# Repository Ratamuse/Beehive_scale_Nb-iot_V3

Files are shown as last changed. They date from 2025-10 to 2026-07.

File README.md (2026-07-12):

# ⚖️ Balance Connectée NB-IoT  
### Système de pesée autonome, étanche et solaire basé sur TTGO SIM7080G







---

## 📚 Table des matières

1. [Présentation du projet](#presentation-du-projet)
2. [Composants — Boîtier électronique](#liste-des-composants-boitier-electronique)
3. [Composants — Structure de la balance](#liste-des-composants-structure-de-la-balance)
4. [Estimation des coûts (5 stations et 10 balances)](#estimation-des-couts-5-stations-et-10-balances)
5. [Étapes d’assemblage](#etapes-dassemblage)
6. [Téléchargement](#telechargement)
7. [Firmware](#firmware)
8. [Mode d'emploi](#mode-demploi)
9. [Partie Web et IoT](#web-iot)
10. [Licence](#licence)
11. [Auteur](#auteur)

---

## 🧠 Présentation du projet

Balances connectées au réseau **NB-IoT** via la carte **TTGO SIM7080G** de LilyGO.  
Cette carte embarque :

- un **MCU ESP32-S3**
- un modem **NB-IoT SIM7080G**
- un **chargeur solaire** pour batterie **18650 Li-Ion**
- un **GPS**
- une **carte SD** pour le stockage local des données

Les balances sont branchées à la TTGO via des convertisseurs **ADC 24 bits HX711**.

Pour faciliter les branchements, un **circuit imprimé dédié** est disponible en **2 versions** :

- une version à **2 convertisseurs HX711**, pour brancher jusqu’à **2 balances**
- une version à **4 convertisseurs HX711**, pour brancher jusqu’à **4 balances**

sur une même station.

Il comprend également :

- des connecteurs pour brancher une sonde **DS18B20** (température) ou **SHT41** (température et humidité), pour mesurer les conditions à l’extérieur du boîtier, voire à l’intérieur de la ruche
- un connecteur pour brancher un **pluviomètre à augets basculants**
- tous les autres connecteurs nécessaires (balances, bouton Wi-Fi, ON/OFF, LED)
- un **Attiny202** servant de watchdog à l'**ESP32-S3** en cas de plantage, et de compteur pour le pluviomètre
- un **capteur gyroscopique** pour détecter un vol
- un capteur **Bosch BME280** pour connaître la température, l’humidité à l’intérieur du boîtier et la pression atmosphérique
- un module **RTC (temps réel)** permettant de connecter en **Bluetooth** plusieurs stations esclaves à une station maîtresse sur un même rucher, une seule carte SIM étant ainsi nécessaire par rucher

👉 Ce circuit imprimé est à souder sur la carte **TTGO SIM7080G**.

🌐 Un serveur web embarqué vous permet de calibrer vos balances et de configurer l’adresse et le port pour vos messages MQTT.

<p align="center">
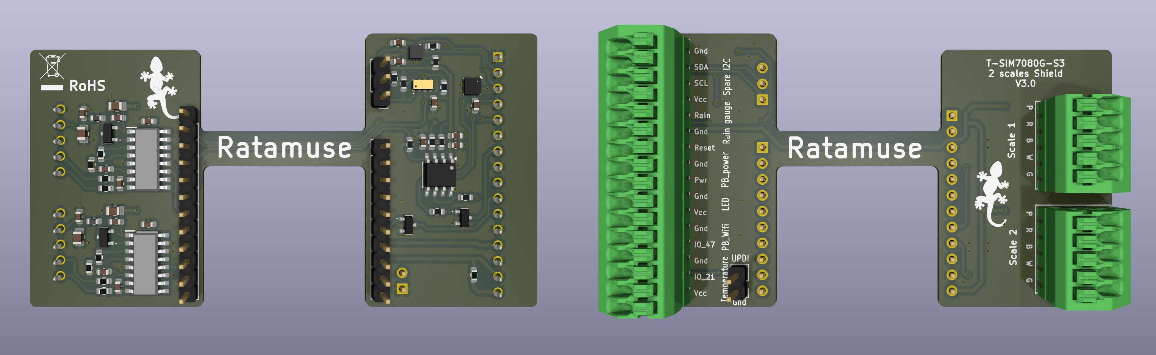
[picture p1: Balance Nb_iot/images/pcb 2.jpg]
  
  
</p>

<p align="center">
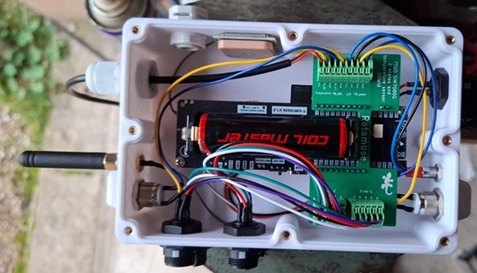
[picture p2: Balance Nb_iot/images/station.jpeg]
  
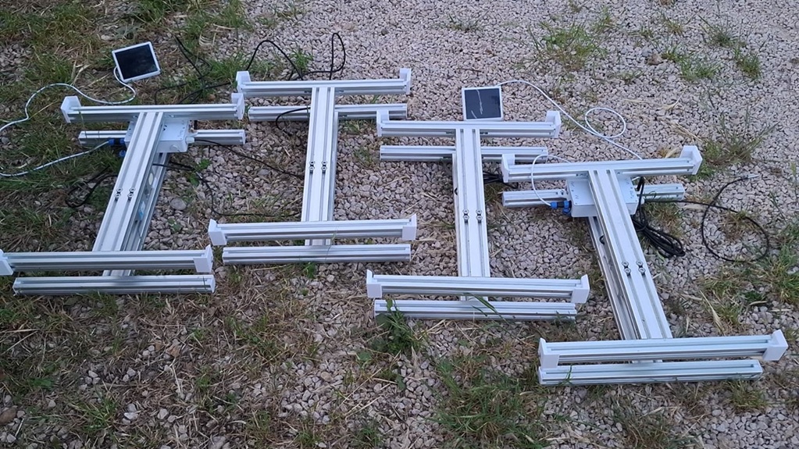
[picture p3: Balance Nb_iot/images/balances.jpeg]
  
</p>

---

## 🧩 Liste des composants – Boîtier électronique

| Image | Composant | Description | Qté | Remarques |
|:--:|---|---|:--:|---|
|  | **Carte TTGO SIM7080G (LilyGO)** | Module principal NB-IoT + ESP32 | 1 | Communication + gestion énergie |
|  | **PCB Beehive_Scale — Version 2 canaux** | Interface capteurs de charge (2× HX711) | 1 | Jusqu’à 2 balances par station |
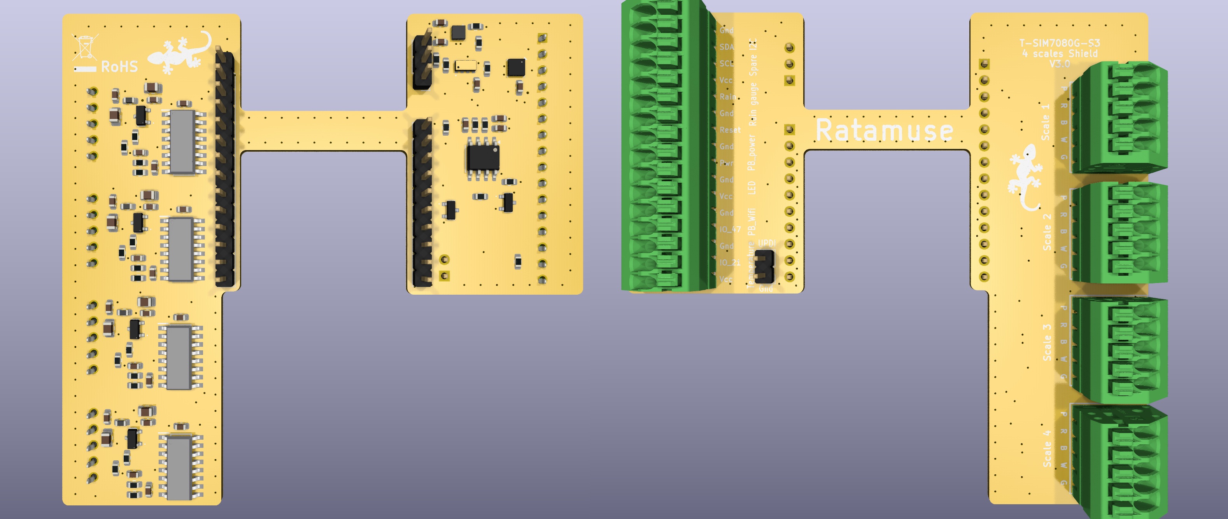
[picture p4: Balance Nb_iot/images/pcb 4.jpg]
|  | **PCB Beehive_Scale — Version 4 canaux** | Interface capteurs de charge (4× HX711) | 1 | Jusqu’à 4 balances par station |
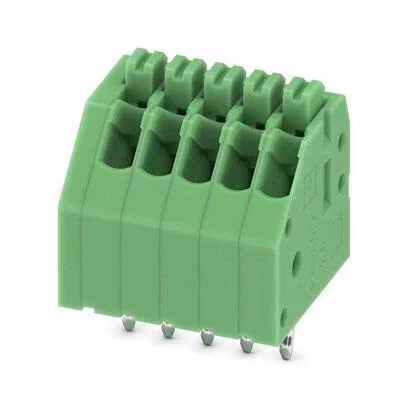
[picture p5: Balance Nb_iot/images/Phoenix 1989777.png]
|  | **Bornier Phoenix 1989777 (5 broches)** | Connexions capteurs | 2 | À souder sur le PCB |
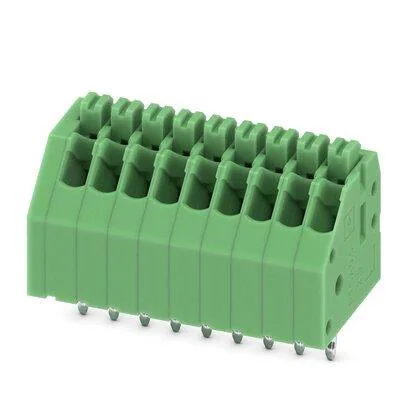
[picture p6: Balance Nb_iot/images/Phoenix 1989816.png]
|  | **Bornier Phoenix 1989816 (9 broches)** | Connexions capteurs | 1 | À souder sur le PCB |
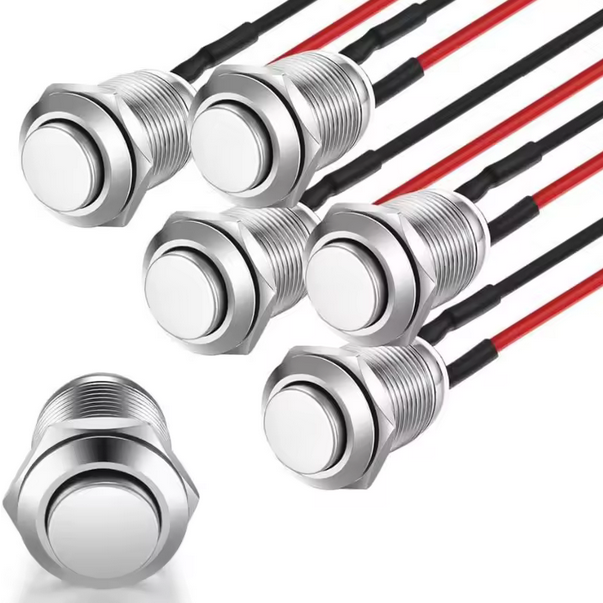
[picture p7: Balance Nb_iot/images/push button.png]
|  | **Boutons poussoirs 12 mm** | Reset / calibration | 2 | Étanches IP67 |
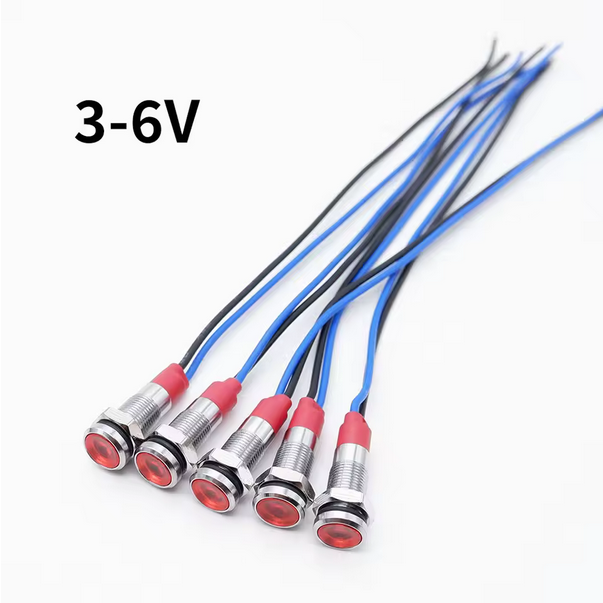
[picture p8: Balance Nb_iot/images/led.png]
|  | **LED 6 mm** | Indication d’état | 1 |  |
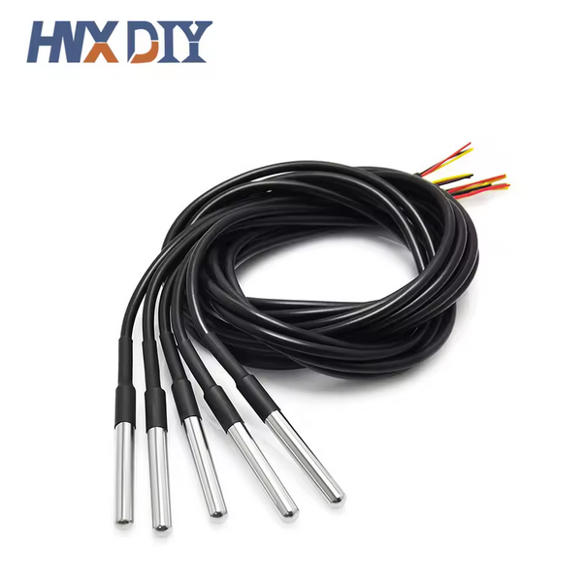
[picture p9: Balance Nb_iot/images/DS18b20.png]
|  | **Sonde DS18B20** | Température ambiante | 1 |  |
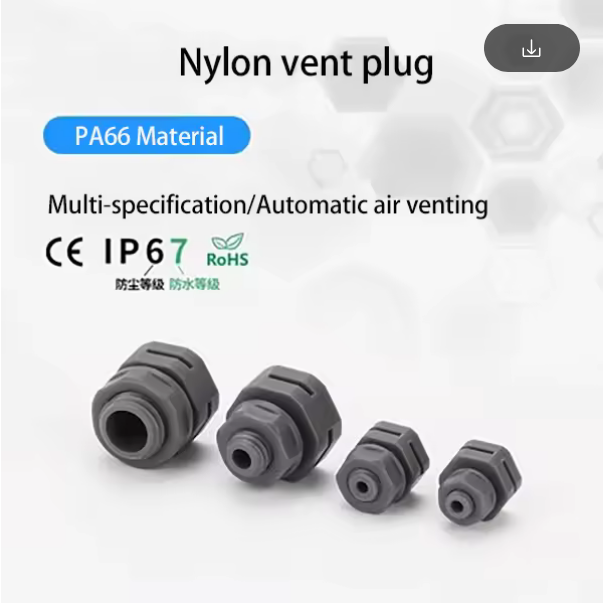
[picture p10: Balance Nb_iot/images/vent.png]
|  | **Soupape d’équilibrage** | Évite la condensation | 1 | IP67 |
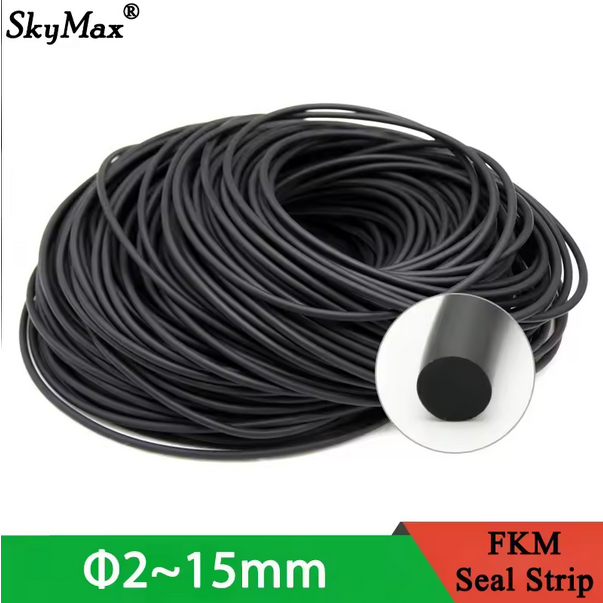
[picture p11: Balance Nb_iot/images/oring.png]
|  | **Joint torique Ø2 mm** | Étanchéité couvercle | 1 | Silicone ou nitrile |
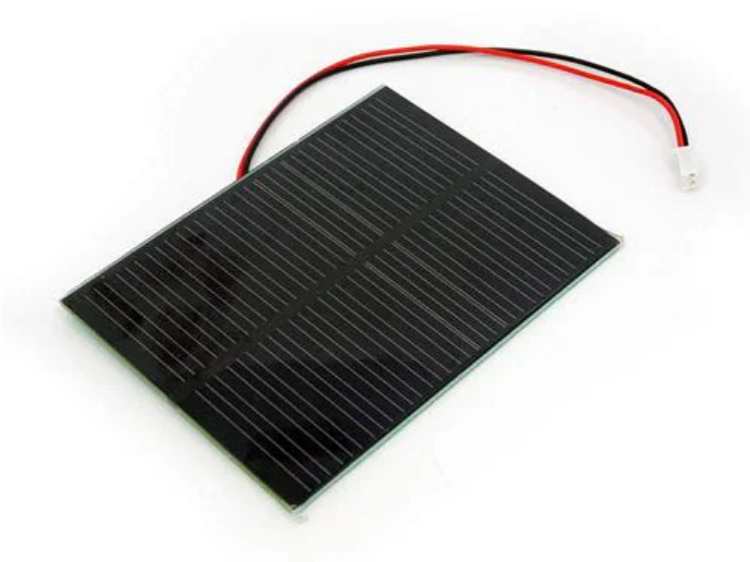
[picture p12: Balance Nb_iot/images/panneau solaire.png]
|  | **Panneau solaire 1W / 6V** | Alimentation solaire | 1 | ~100×80 mm |
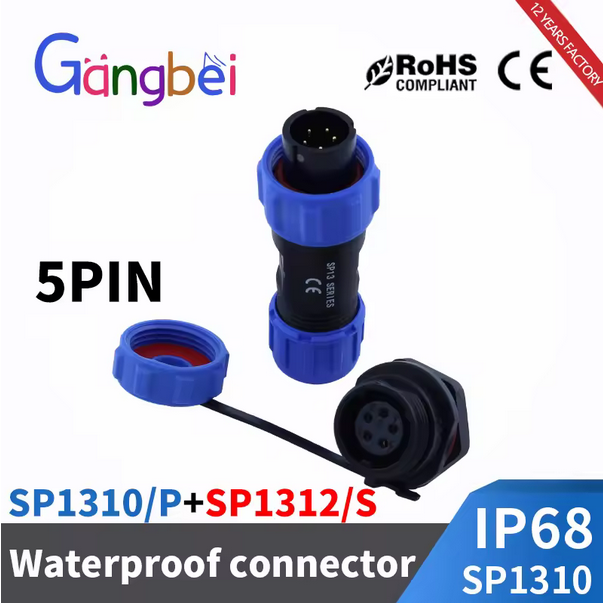
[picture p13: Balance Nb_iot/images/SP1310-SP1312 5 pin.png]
|  | **Connecteurs étanches 5 pins** | Connexion balance | 2 | IP67 |
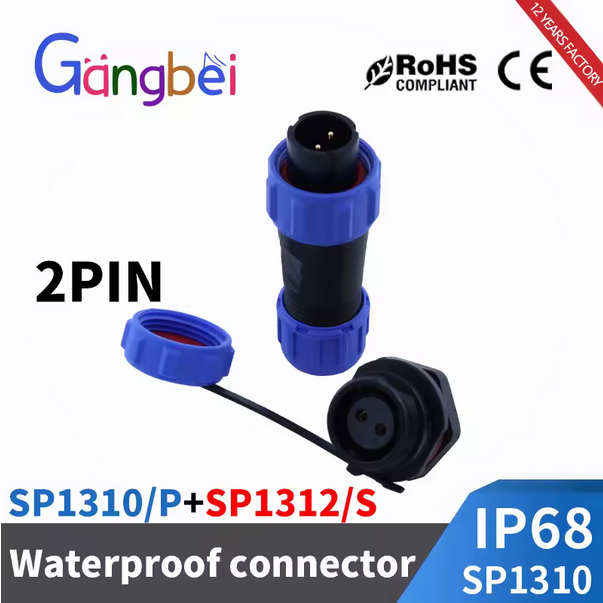
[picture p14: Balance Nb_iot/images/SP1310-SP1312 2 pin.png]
|  | **Connecteurs étanches 2 pins** | Connexion solaire | 1 | IP67 |
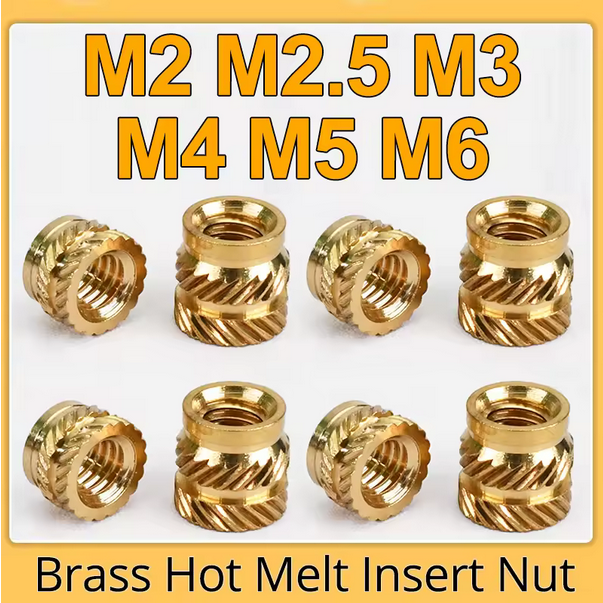
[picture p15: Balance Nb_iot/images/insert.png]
|  | **Inserts laiton ** | Fixation boîtier 3D | 6 | M3 (diam 4.2mm, hauteur 5mm), à insérer à chaud |
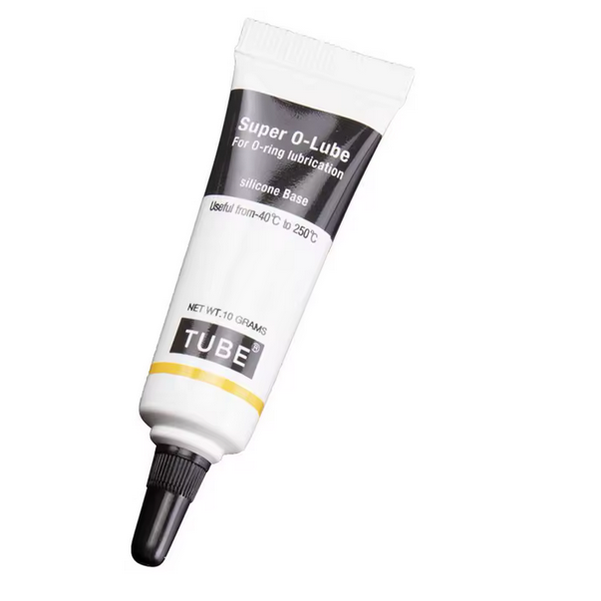
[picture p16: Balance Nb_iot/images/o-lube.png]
|  | **Graisse silicone** | Lubrification joints | - | Améliore l’étanchéité |
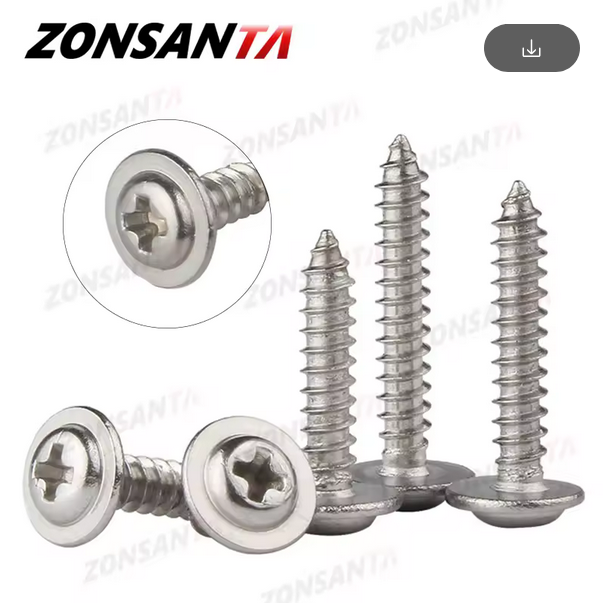
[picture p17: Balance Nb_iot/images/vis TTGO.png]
|  | **Vis de fixation TTGO** | Fixation carte | 4 | M2 5mm Inox |
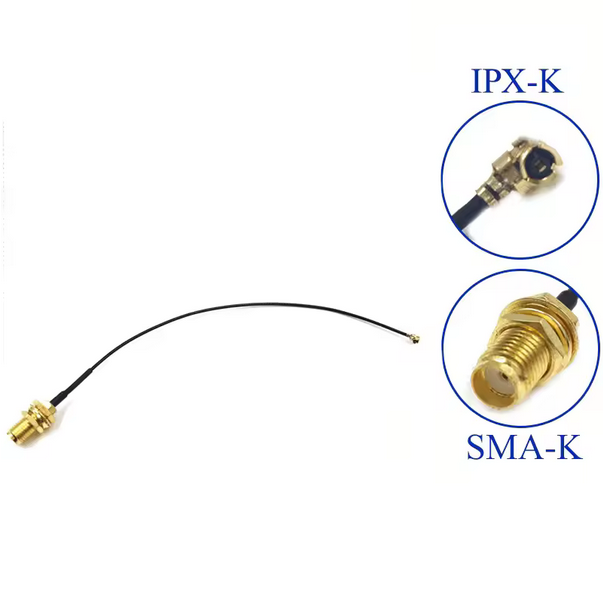
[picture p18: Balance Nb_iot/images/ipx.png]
|  | **Câble IPX → SMA-K (5 cm)** | Liaison antenne | 1 | Pour module SIM7080G |
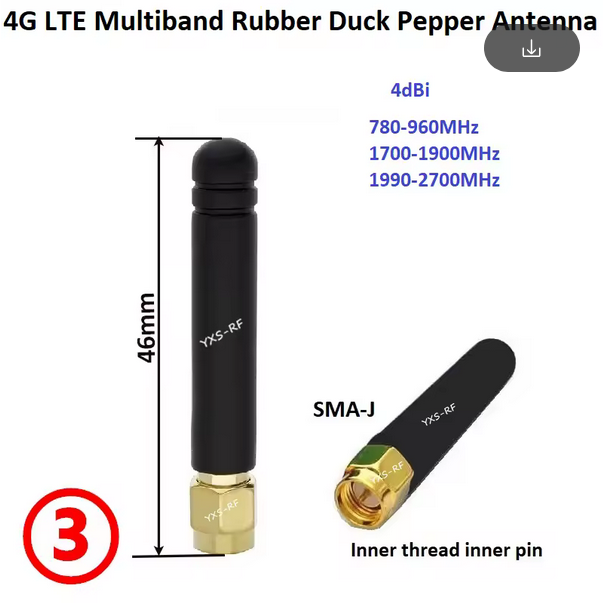
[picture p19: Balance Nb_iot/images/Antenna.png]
|  | **Antenne NB-IoT / 4G** | Transmission réseau | 1 | SMA externe |
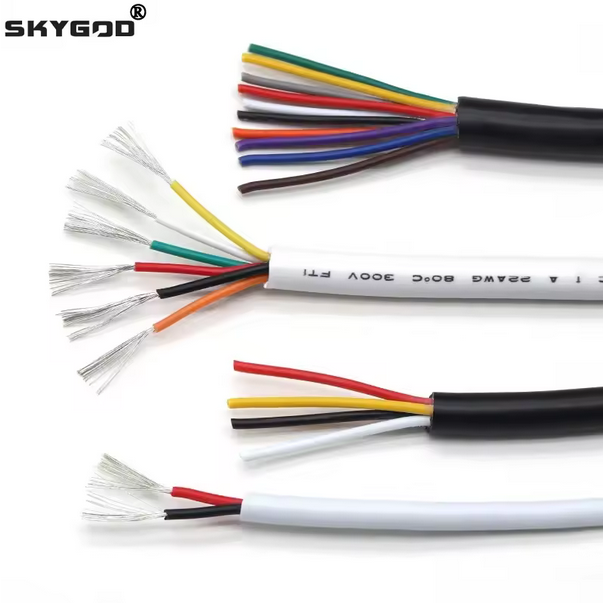
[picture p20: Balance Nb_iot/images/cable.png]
|  | **Câble 2 brins (2 m)** | Connexion solaire | 1 |  |
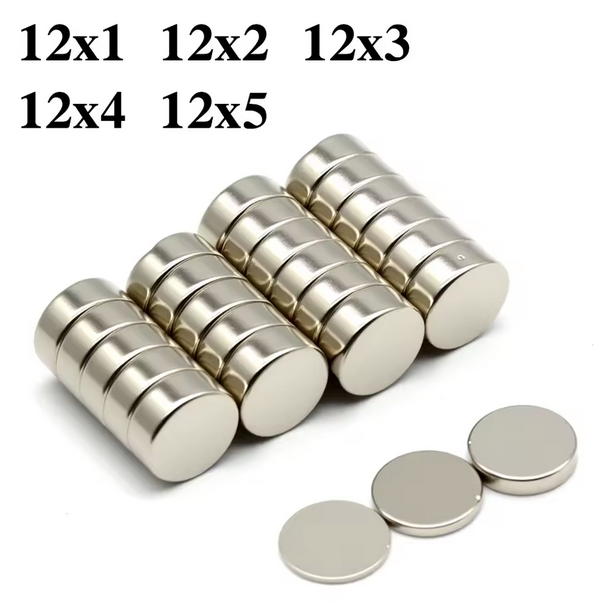
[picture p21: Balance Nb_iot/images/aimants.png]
|  | **Aimants 12×3 mm** | Fixation panneau solaire | 2 | Néodyme |
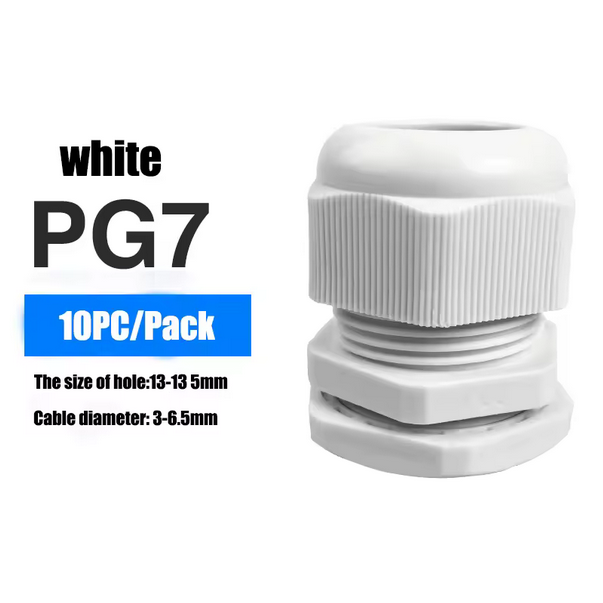
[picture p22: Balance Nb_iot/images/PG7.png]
|  | **Presse-étoupe PG7 (12 mm)** | Passage câble | 1 | IP68 |
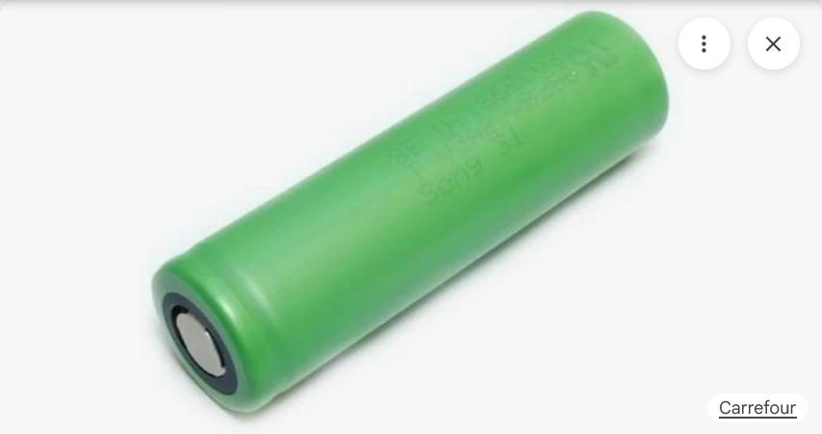
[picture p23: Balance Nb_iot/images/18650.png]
|  | **Batterie Li-Ion 18650 (3000 mAh)** | Alimentation interne | 1 |  |
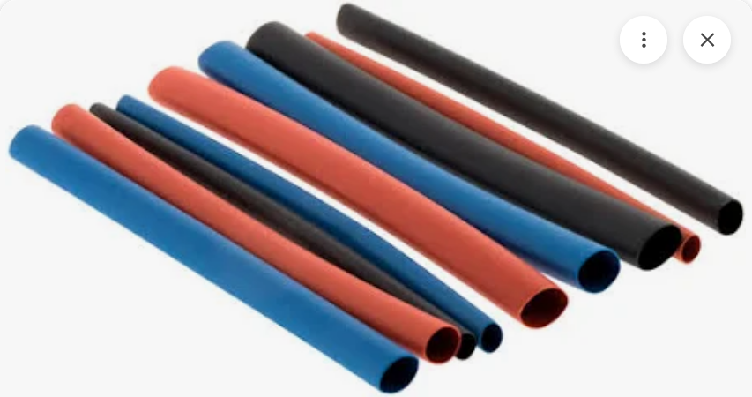
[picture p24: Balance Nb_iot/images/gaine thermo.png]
|  | **Gaine thermorétractable** | Protection connexions | - |  |
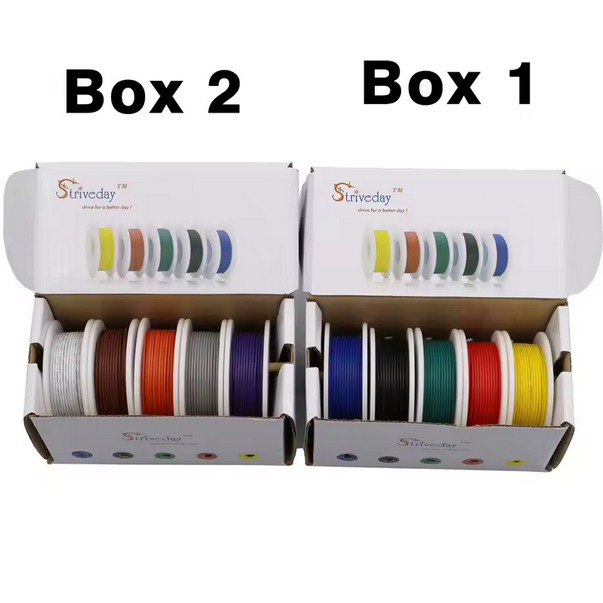
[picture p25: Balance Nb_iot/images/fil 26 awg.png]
|  | **Fils AWG26** | Câblage interne | - | LED, boutons |
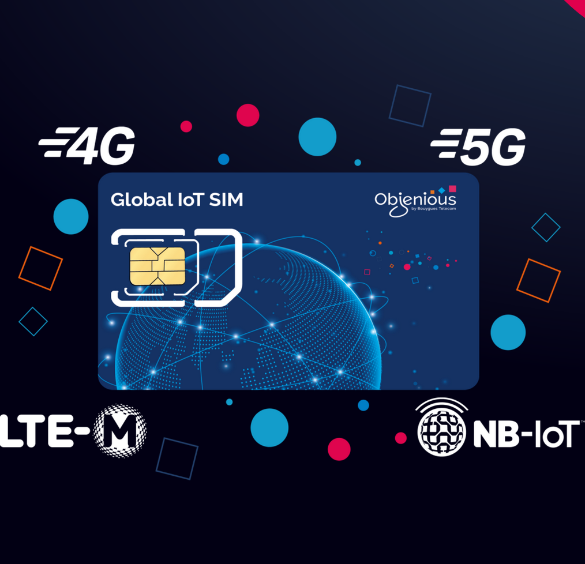
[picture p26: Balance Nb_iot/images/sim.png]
|  | **Carte SIM NB-IoT** | Accès réseau | 1 | M2M ou prépayée |
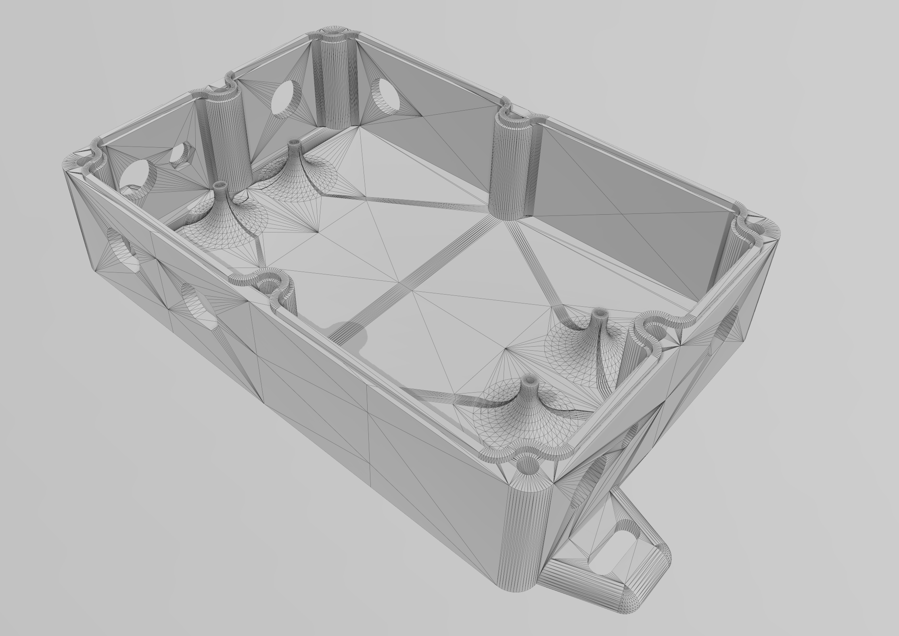
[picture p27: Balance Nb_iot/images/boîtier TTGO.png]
|  | **Boîtier imprimé 3D (PETG)** | Conteneur principal | 1 | Étanche et modulaire |

---

## ⚖️ Liste des composants – Structure de la balance

| Image | Composant | Description | Qté | Remarques |
|:--:|---|---|:--:|---|
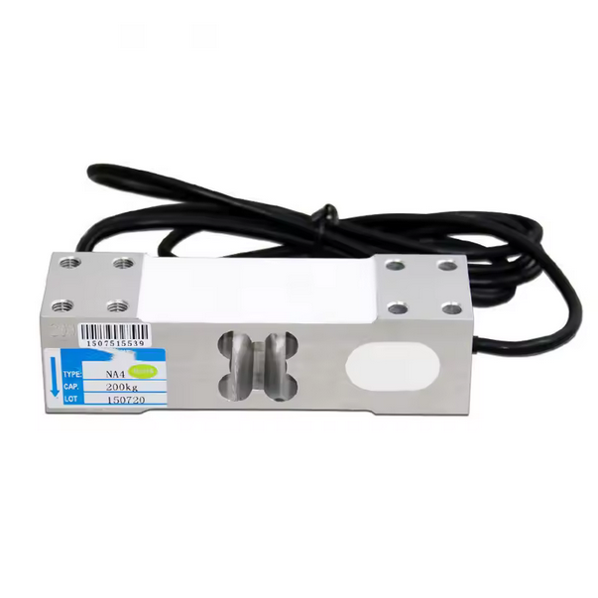
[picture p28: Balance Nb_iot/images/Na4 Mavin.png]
|  | **Capteurs de charge NA4 Mavin** | Mesure du poids | 2 | 100 ou 200 kg |
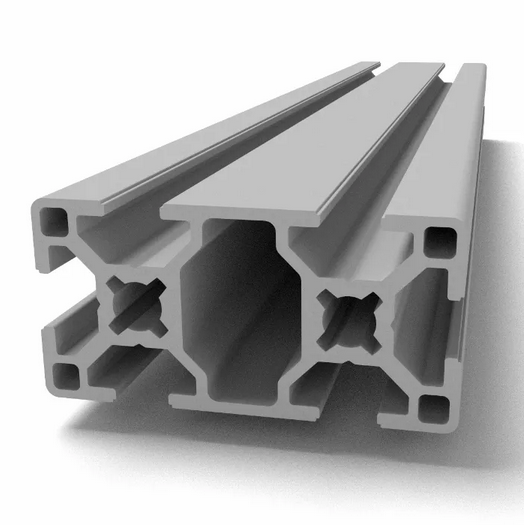
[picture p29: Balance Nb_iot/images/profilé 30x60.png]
|  | **Profilé alu 30×60 Type B** | Structure  | 2 | 480 mm (format plancher Nicot) |
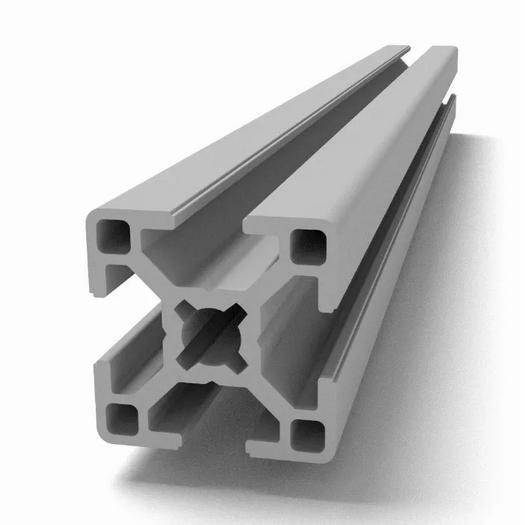
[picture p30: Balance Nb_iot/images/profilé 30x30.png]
|  | **Profilé alu 30×30 Type B** | Structure  | 4 | 430 mm (format plancher Nicot) |
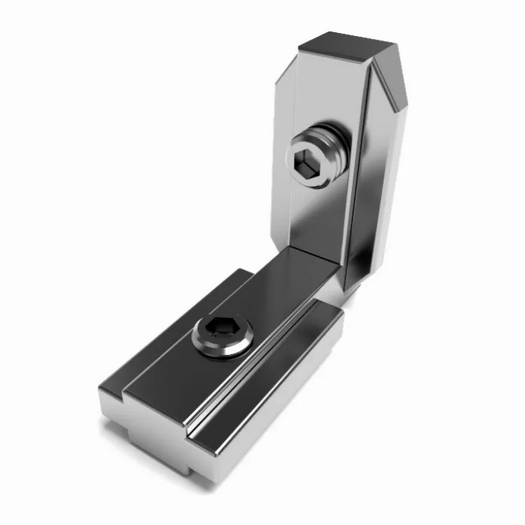
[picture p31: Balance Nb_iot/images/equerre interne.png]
|  | **Équerres internes** | Assemblage mécanique | 8 | Rainure 8 M6 |
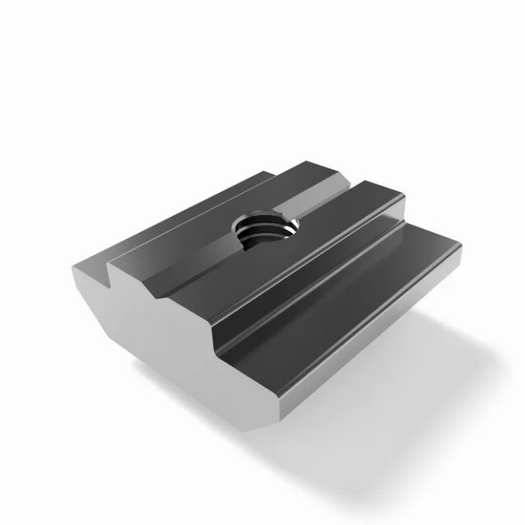
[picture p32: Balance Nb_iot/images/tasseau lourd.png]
|  | **Tasseaux lourds B-Type M5** | Fixation structurelle | 2 | Maintien |
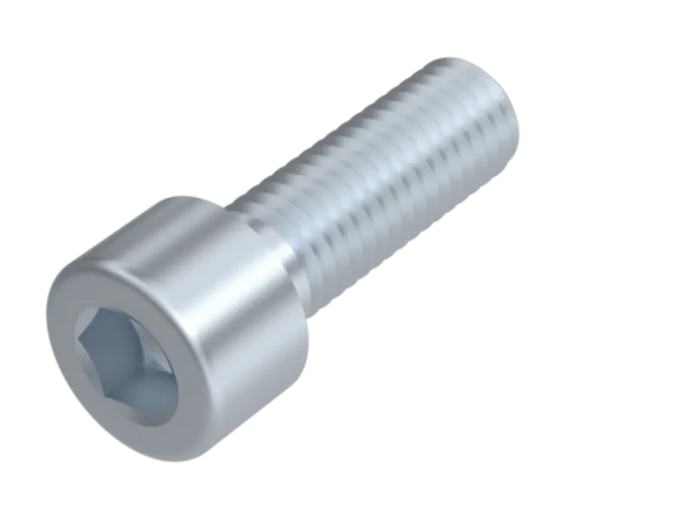
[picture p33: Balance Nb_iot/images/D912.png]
|  | **Visserie DIN 912** | M8x16 / M8x45 / M5x8 | - | Inox |
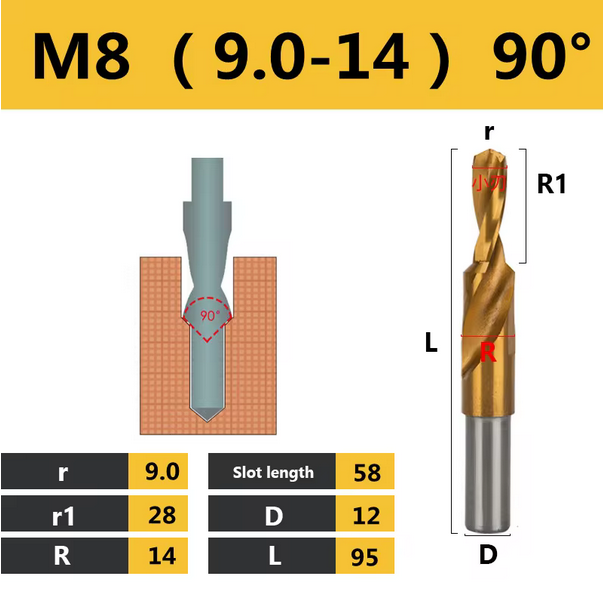
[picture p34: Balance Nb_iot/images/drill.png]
|  | **Foret étagé M8 (9–14 mm)** | Perçage profilés | 1 | |
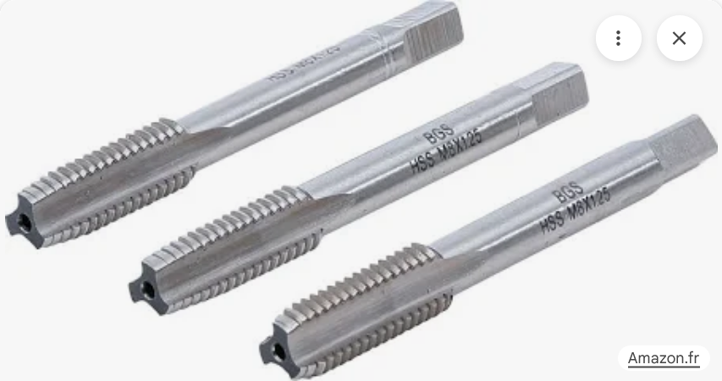
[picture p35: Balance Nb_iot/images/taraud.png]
|  | **Taraud M8** | Filetage profilés | 1 |  |
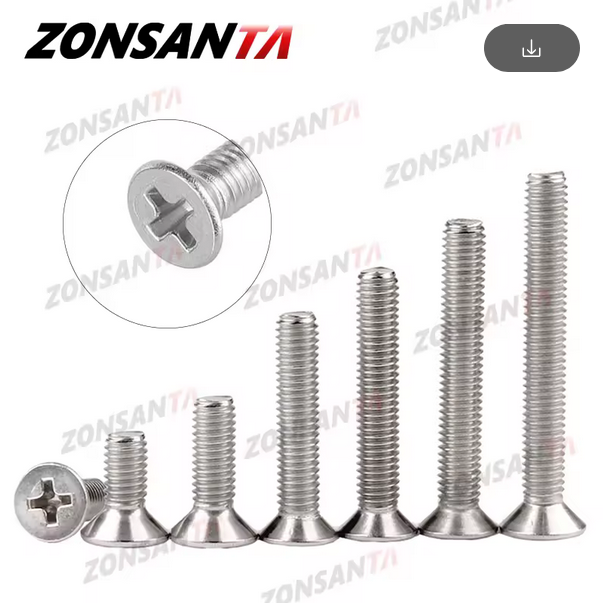
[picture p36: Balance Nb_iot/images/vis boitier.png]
|  | **Vis de boîtier** | Fixation boîtier | 4 | Inox |
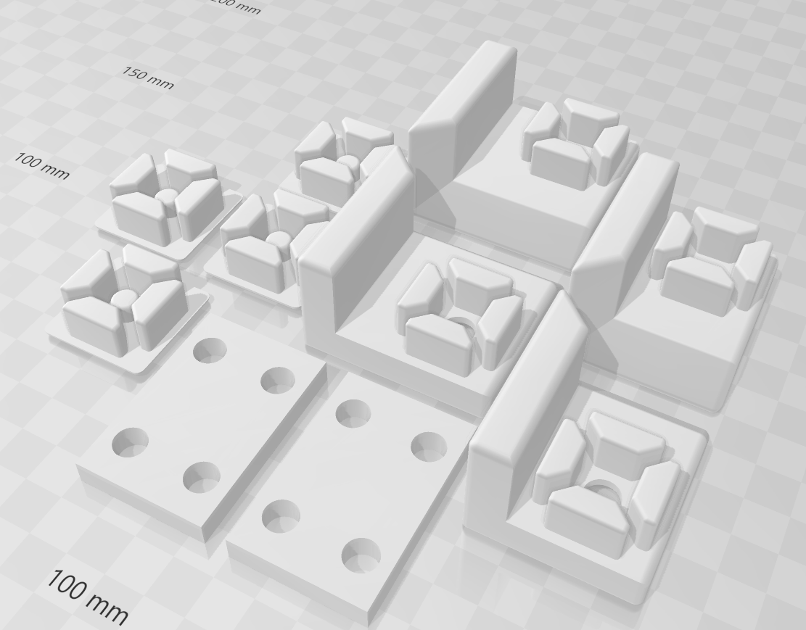
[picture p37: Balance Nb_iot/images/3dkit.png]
|  | **Kit impression 3D (PETG)** | Pièces structurelles | 1 | Supports, entretoises |

---

## 💰 Estimation des coûts — 5 stations et 10 balances (janvier 2026)

> ⚠️ Estimation indicative : les prix varient selon fournisseurs, quantités et frais de port.

### Balances (x10)

#### Motedis.fr

| Élément | Coût |
|---|---:|
| Kit Motedis | 465 € TTC |

#### Aliexpress

| Élément | Coût |
|---|---:|
| Connecteurs SP13 2 pins | 11 € |
| Connecteurs SP13 5 pins | 28 € |
| Peson 200 kg | 250 € |
| **Sous-total Balances** | **754 €** |

---

### Stations (x5)

#### Aliexpress

| Élément | Coût |
|---|---:|
| Carte TTGO SIM7080G | 200 € |
| Sonde température DS18B20 | 4,3 € |
| Câble IPX | 2,5 € |
| Antenne 4G | 4,5 € |
| Câble panneau solaire | 7 € |
| Aimant | 4,2 € |
| Reniflard | 4 € |
| Bouton poussoir | 5 € |
| Vis boîtier | 1,85 € |
| Vis TTGO | 1,8 € |
| LED rouge 3V | 6 € |
| Joint torique 2 mm × 5 m | 3,3 € |
| Câble 28 AWG | 1 € |
| Gaine thermo | 1 € |
| Colliers | 0,5 € |
| Inserts laiton | 1,8 € |

#### Mouser

| Élément | Coût |
|---|---:|
| Panneau solaire 1W | 20,5 € |
| Connecteurs 5 pins | 8 € |
| Connecteurs 12 pins | 9,7 € |
| FDP | 20 € *(ou 0 € si commande > 50 €)* |

#### JLCPCB

| Élément | Coût |
|---|---:|
| PCB | 54 € |
| *(108 € pour 10 cartes)* | |

#### Divers

| Élément | Coût |
|---|---:|
| 5 SIM NB-IoT Bouygues Telecom | 90 € |
| Impression 3D PETG | 40 € |
| Vernis de tropicalisation | 5 € |

---

### Total

| Total | Coût |
|---|---:|
| **Total global** | **1230 €** |
| **Coût moyen (par station)** | **246 €** |

---

## ⚙️ Étapes d’assemblage

*A faire.*

---

## 📥 Téléchargements

### 🔌 Fichiers PCB

- **Dossier PCB (schémas + gerbers + BOM)**  
Ancien modèle, 2 balances, un attiny202 pour le watchdog
  👉 https://github.com/Ratamuse/Beehive_scale_Nb-iot_V3/tree/main/Balance%20Nb_iot/PCB

### 🧩 Fichiers STL pour impression 3D

- **Dossier STL**  
  👉 https://github.com/Ratamuse/Beehive_scale_Nb-iot_V3/tree/main/Balance%20Nb_iot/Fichiers%20stl

---

## 💾 Firmware

- **Dossier Firmware**  
  👉 https://github.com/Ratamuse/Beehive_scale_Nb-iot_V3/tree/main/Balance%20Nb_iot/Firmware

---

## 📘 Mode d'emploi

Pour consulter le **mode d'emploi complet** de la Balance Connectée NB-IoT, rendez-vous ici :  
👉 [Mode d'emploi](https://github.com/Ratamuse/Beehive_scale_Nb-iot_V3/tree/main/Balance%20Nb_iot/Mode%20d'emploi)

## 🌐 Partie Web et IoT

La **balance connectée** communique via un **serveur web embarqué** et envoie ses données au format **MQTT** vers un **broker Mosquitto**.  

Les données envoyées par MQTT comprennent :

- ⚖️ **Poids** : mesures des deux ou quatre balances  
- 🌡️ **Température** : température ambiante mesurée par la sonde DS18B20  
- 🔋 **Batterie** : pourcentage de charge de la batterie interne  
- 📶 **Signal NB-IoT** : force du signal réseau  
- 📍 **Position** : coordonnées GPS exactes et position approximative (mise à jour 1 fois par jour)

Voici le flux des données :  

- 📨 **Envoi des mesures** : la balance publie ses données en MQTT.  
- ⚙️ **Traitement** : les messages peuvent être formatés et transformés par **Telegraf**.  
- 🗄️ **Stockage** : les données sont enregistrées dans une **base InfluxDB v2**.  
- 📊 **Visualisation** : Grafana permet de suivre les mesures en **temps réel** et d’afficher les historiques.  

> 💡 Exemple : les fichiers MQTT peuvent être traités comme vous le souhaitez, selon vos besoins.  

Toutes les données peuvent être :  

- 🖥️ **Stockées localement** sur un serveur dédié.  
- ☁️ Ou hébergées **dans le cloud** via un prestataire pour un accès distant et sécurisé.  

Cette architecture flexible permet d’**adapter le système** à différents besoins, tout en gardant la possibilité d’une **supervision centralisée ou locale**.

🌍 Un **site internet** est également disponible pour recevoir et visualiser vos données : gratuit pour les fonctionnalités de base, et entre **20 et 30€** par an pour l'accès à toutes les fonctionnalités (essai gratuit de **15 jours**). 
👉 [monrucher.ratamuse.fr](https://monrucher.ratamuse.fr)

## 📜 Licence

Ce projet est distribué sous licence **MIT**.  
Vous êtes libres de l’utiliser, le modifier et le partager, tant que la licence originale est conservée.

---

## 👤 Auteur

**Auteur :** [Ratamuse](https://github.com/Ratamuse)  
**Projet :** Balance Connectée NB-IoT  
**Version :** v1.0  
**Année :** 2026

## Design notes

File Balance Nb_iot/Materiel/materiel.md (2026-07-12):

# ⚖️ Balance Connectée NB-IoT  
### Système de pesée autonome, étanche et solaire basé sur TTGO SIM7080G







---

## 📚 Table des matières

1. [Présentation du projet](#-présentation-du-projet)
2. [Composants — Boîtier électronique](#-liste-des-composants--boîtier-électronique)
3. [Composants — Structure de la balance](#-liste-des-composants--structure-de-la-balance)
4. [Estimation des coûts (janvier 2026)](#-estimation-des-coûts--5-stations-et-10-balances-janvier-2026)
5. [Assemblage](#-étapes-dassemblage)
6. [Téléchargement](#-téléchargement)
7. [Licence](#-licence)
8. [Auteur](#-auteur)

---

## 🧠 Présentation du projet

Balances connectées au réseau **NB-IoT** via la carte **TTGO SIM7080G** de LilyGO.  
Cette carte embarque :

- un **MCU ESP32-S3**
- un modem **NB-IoT SIM7080G**
- un **chargeur solaire** pour batterie **18650 Li-Ion**
- un lecteur de **carte microSD** utile au projet

Les balances sont branchées à la TTGO via des convertisseurs **ADC 24 bits HX711**.  
Une sonde de température **DS18B20** complète l’ensemble.

Pour faciliter les branchements, un **circuit imprimé dédié** est disponible. Il comprend :

- 2 convertisseurs **HX711**
- tous les connecteurs nécessaires (balances, sonde, bouton Wi-Fi, ON/OFF, LED)
- un **watchdog externe** pour relancer la carte principale en cas de plantage

👉 Ce circuit imprimé est à souder sur la carte **TTGO SIM7080G**.

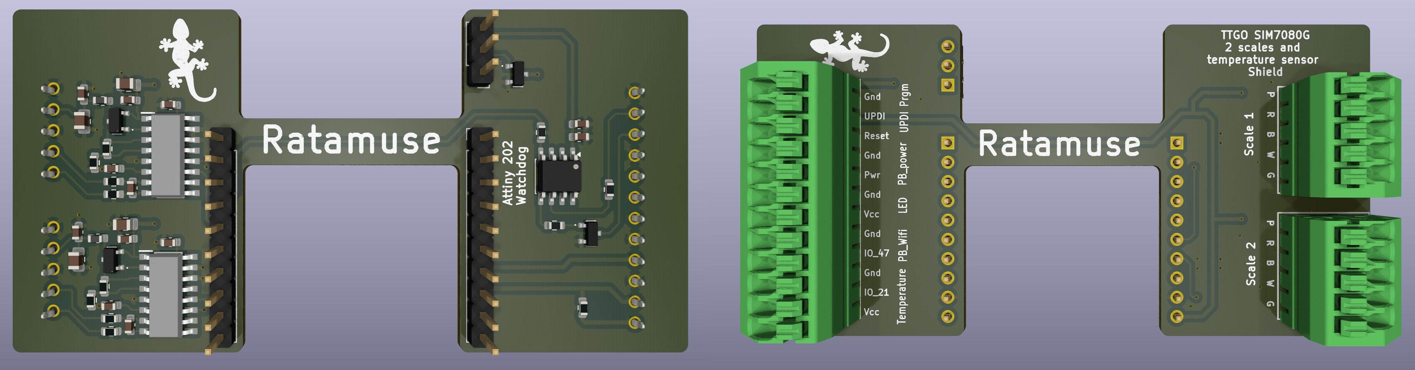
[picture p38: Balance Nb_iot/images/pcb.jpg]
PCB

TTGO

---

## 🧩 Liste des composants – Boîtier électronique

| Image | Composant | Description | Qté | Remarques |
|:--:|---|---|:--:|---|
|  | **Carte TTGO SIM7080G (LilyGO)** | Module principal NB-IoT + ESP32 | 1 | Communication + gestion énergie |
|  | **PCB Beehive_Scale** | Interface capteurs de charge | 1 | Spécifique au projet |
|  | **Bornier Phoenix 1989777 (5 broches)** | Connexions capteurs | 2 | À souder sur le PCB |
|  | **Bornier Phoenix 1989816 (9 broches)** | Connexions capteurs | 1 | À souder sur le PCB |
|  | **Boutons poussoirs 12 mm** | Reset / calibration | 2 | Étanches IP67 |
|  | **LED 6 mm** | Indication d’état | 1 | Couleur libre |
|  | **Sonde DS18B20** | Température ambiante | 1 | Étanche |
|  | **Soupape d’équilibrage** | Évite la condensation | 1 | IP67 |
|  | **Joint torique Ø2 mm** | Étanchéité couvercle | 1 | Silicone ou nitrile |
|  | **Panneau solaire 1W / 6V** | Alimentation solaire | 1 | ~100×80 mm |
|  | **Connecteurs étanches 5 pins** | Connexion balance | Plusieurs | IP67 |
|  | **Connecteurs étanches 2 pins** | Connexion solaire | Plusieurs | IP67 |
|  | **Inserts laiton M3** | Fixation boîtier 3D | 6 | À insérer à chaud |
|  | **Graisse silicone** | Lubrification joints | - | Améliore l’étanchéité |
|  | **Vis de fixation TTGO** | Fixation carte | 4 | Inox |
|  | **Câble IPX → SMA-K (5 cm)** | Liaison antenne | 1 | Pour module SIM7080G |
|  | **Antenne NB-IoT / 4G** | Transmission réseau | 1 | SMA externe |
|  | **Câble 2 brins (2 m)** | Connexion solaire | 1 | Étanche |
|  | **Aimants 12×3 mm** | Fixation panneau solaire | 2 | Néodyme |
|  | **Presse-étoupe PG7 (12 mm)** | Passage câble | 1 | IP68 |
|  | **Batterie Li-Ion 18650 (3000 mAh)** | Alimentation interne | 1 | Avec BMS |
|  | **Gaine thermorétractable** | Protection connexions | - | Étanchéité |
|  | **Fils AWG26** | Câblage interne | - | LED, boutons |
|  | **Vis de boîtier** | Fixation boîtier | 4 | Inox M3x12mm |
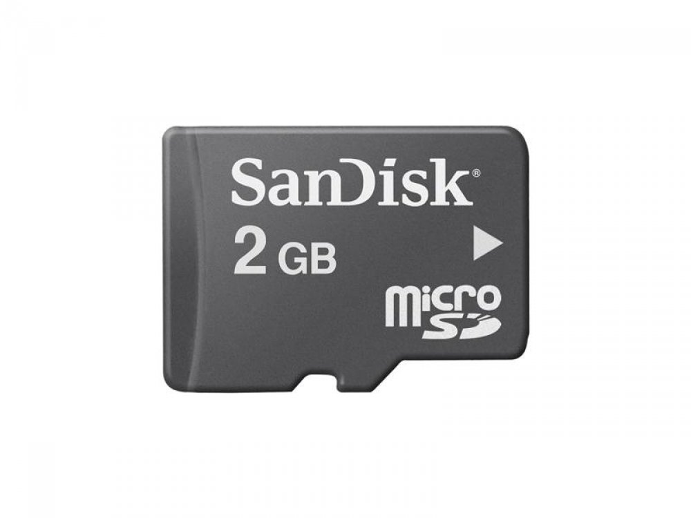
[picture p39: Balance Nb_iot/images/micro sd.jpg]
|  | **Carte microSD 16 Go** | Stockage local | 1 | FAT32 |
|  | **Carte SIM NB-IoT** | Accès réseau | 1 | M2M ou prépayée |
|  | **Boîtier imprimé 3D (PETG)** | Conteneur principal | 1 | Étanche et modulaire |

---

## ⚖️ Liste des composants – Structure de la balance

| Image | Composant | Description | Qté | Remarques |
|:--:|---|---|:--:|---|
|  | **Capteurs de charge NA4 Mavin** | Mesure du poids | 2 | 100 ou 200 kg |
|  | **Profilé alu 30×60 Type B** | Structure principale | 2 | 480 mm |
|  | **Profilé alu 30×30 Type B** | Structure secondaire | 4 | 430 mm |
|  | **Équerres internes** | Assemblage mécanique | 8 | Rainure 8 M6 |
|  | **Tasseaux lourds B-Type M5** | Fixation structurelle | 2 | Maintien |
|  | **Visserie DIN 912** | M8x16 / M8x45 / M5x8 | - | Inox |
|  | **Foret étagé M8 (9–14 mm)** | Perçage profilés | 1 | |
|  | **Taraud M8** | Filetage profilés | 1 | Montage précis |
|  | **Kit impression 3D (PETG)** | Pièces structurelles | 1 | Supports, entretoises |

---

## 💰 Estimation des coûts — 5 stations et 10 balances (janvier 2026)

> ⚠️ Estimation indicative : les prix varient selon fournisseurs, quantités et frais de port.

### Balances (x10)

#### Motedis.fr

| Élément | Coût |
|---|---:|
| Kit Motedis | 465 € TTC |

#### Aliexpress

| Élément | Coût |
|---|---:|
| Connecteurs SP13 2 pins | 11 € |
| Connecteurs SP13 2 pins | 28 € |
| Peson 200 kg | 250 € |
| **Sous-total Balances** | **754 €** |

---

### Stations (x5)

#### Aliexpress

| Élément | Coût |
|---|---:|
| Carte TTGO SIM7080G | 200 € |
| Sonde température DS18B20 | 4,3 € |
| Câble IPX | 2,5 € |
| Antenne 4G | 4,5 € |
| Câble panneau solaire | 7 € |
| Aimant | 4,2 € |
| Reniflard | 4 € |
| Bouton poussoir | 5 € |
| Vis boîtier | 1,85 € |
| Vis TTGO | 1,8 € |
| LED rouge 3V | 6 € |
| Joint torique 2 mm × 5 m | 3,3 € |
| Câble 28 AWG | 1 € |
| Gaine thermo | 1 € |
| Colliers | 0,5 € |
| Inserts laiton | 1,8 € |

#### Mouser

| Élément | Coût |
|---|---:|
| Panneau solaire 1W | 20,5 € |
| Connecteurs 5 pins | 8 € |
| Connecteurs 12 pins | 9,7 € |
| FDP | 20 € *(ou 0 € si commande > 50 €)* |

#### JLCPCB

| Élément | Coût |
|---|---:|
| PCB | 54 € |
| *(108 € pour 10 cartes)* | |

#### Divers

| Élément | Coût |
|---|---:|
| 5 SIM NB-IoT Bouygues Telecom | 90 € |
| Impression 3D PETG | 40 € |
| Vernis de tropicalisation | 5 € |

---

### Total

| Total | Coût |
|---|---:|
| **Total global** | **1230 €** |
| **Coût moyen (par station)** | **246 €** |

---

## ⚙️ Étapes d’assemblage

*A faire.*

---

## 📥 Téléchargements

### 🔌 Fichiers PCB

- **Dossier PCB (schémas + gerbers + BOM)**  
  👉 https://github.com/Ratamuse/Beehive_scale_Nb-iot_V3/tree/main/Balance%20Nb_iot/PCB

---

### 🧩 Fichiers STL pour impression 3D

- **Dossier STL**  
  👉 https://github.com/Ratamuse/Beehive_scale_Nb-iot_V3/tree/main/Balance%20Nb_iot/Fichiers%20stl

---

## 📜 Licence

Ce projet est distribué sous licence **MIT**.  
Vous êtes libres de l’utiliser, le modifier et le partager, tant que la licence originale est conservée.

---

## 👤 Auteur

**Auteur :** [Ratamuse](https://github.com/Ratamuse)  
**Projet :** Balance Connectée NB-IoT  
**Version :** v1.0  
**Année :** 2025

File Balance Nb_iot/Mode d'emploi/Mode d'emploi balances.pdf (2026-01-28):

# Balances connectées

Le système est composé d’un boîtier rassemblant l’électronique et de 2 balances.

Sur le boîtier :

- Un bouton poussoir ON/OFF
- Un bouton poussoir Wifi
- Une led
- Un connecteur SMA pour une antenne externe
- Une sonde de température DS18b20
- Une soupape à membrane respirante
- Un connecteur 2 broches pour panneau photovoltaïque (PV)
- Un connecteur pour la balance 1 ou A
- Un connecteur pour la balance 2 ou B

Le boîtier est fixé sur la balance A

Pour allumer le système, appuyer sur le bouton ON/OFF pendant deux secondes. La led rouge va clignoter.
Pour éteindre le système, appuyer sur le bouton ON/OFF pendant plus de six secondes. Il n’y a pas de clignotement de la led.

### Serveur web embarqué

Afin de configurer les balances, il faut accéder au serveur web embarqué.
1. Éteindre la balance en appuyant plus de 6 secondes sur le bouton ON/OFF.
2. Appuyer sur le bouton Wifi puis en même temps, appuyer sur le bouton ON/OFF. La led va clignoter, relâcher le bouton Wifi.
3. Recherche le réseau Wifi balanceS1 ou balanceS2
4. Se connecter au réseau wifi avec le mot de passe
123456789
5. Se connecter au serveur en écrivant sur la barre d’adresse d’un navigateur l’adresse IP http://192.168.4.1 (attention à ne pas écrire https://) La page principale s’affiche :

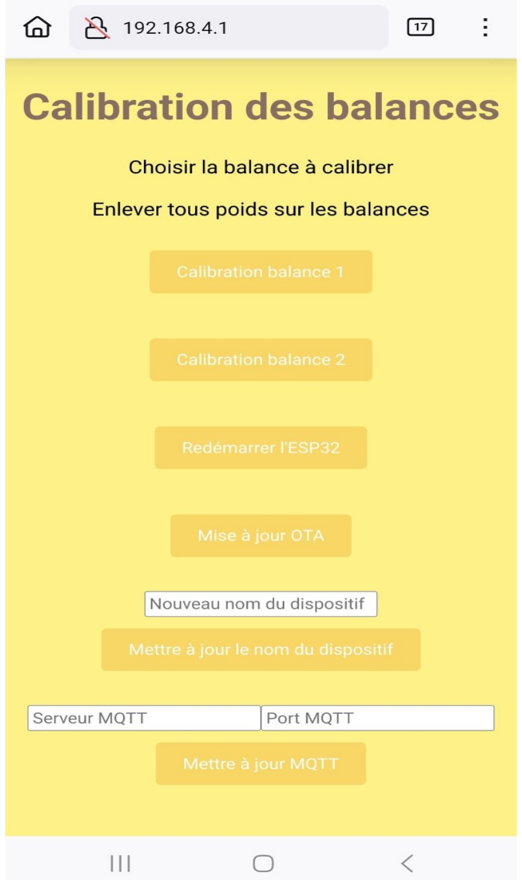
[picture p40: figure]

Si cela ne fonctionne pas, coupez les données 4G du téléphone, le naviagateur peux essayer de se connecter sur le réseau au lieu de se connecter au wifi.
Six actions sont possibles :
Calibrer la balance 1 (A)
Calibrer la balance 2 (B)
Redémarrer la station
Mettre à jour le Firmware (Mise à jour OTA) Changer le nom de la station : S1, S2, S3 etc. Changer l’adresse et le port du serveur MQTT

### Calibration des balances

Avec le temps, le zéro des balances peut dériver. Il est conseillé de calibrer la balance au moins une fois par an. Pour cela :
Pour la balance 1 (A), enlever les poids sur la balance (ruche, saleté, cordons).
Appuyer sur le bouton « Calibration balance 1 »
Une fois la page avec la valeur de l’offset affiché, poser un poid connu sur la balance à calibrer puis rentrer cette valeur en gramme. Ici 4690 grammes.
Valider en appuyant sur le bouton « Entrer »
Une fois la calibration terminée, le facteur de conversion et l’offset sont affichés.
Il y a ensuite deux possibilités, redémarrer la station ou retourner à la page d’accueil du serveur web.
La manipulation est identique pour la balance 2 (ou B)

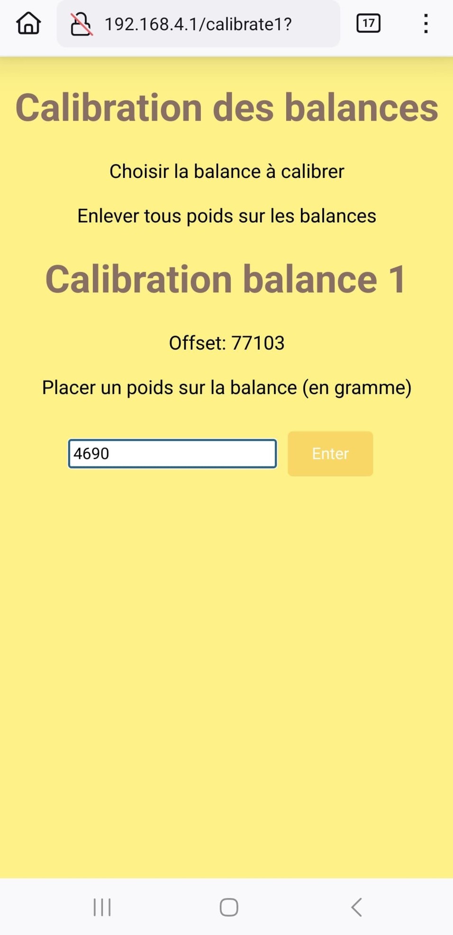
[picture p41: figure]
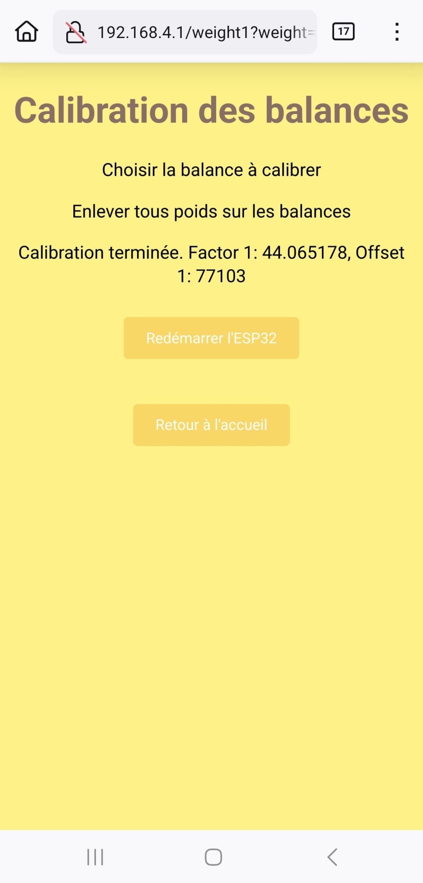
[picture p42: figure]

### Mise à jour OTA (over the air)

Il est possible d’améliorer les performances ou ajouter des fonctionnalités aux balances en mettant à jour le firmware. Pour cela, vous seriez amenés à télécharger un fichier « update.bin » et l’envoyer sur la station.
Pour cela, cliquer sur l’onglet « Mise à jour OTA » sur la page principale puis sur l’onglet « Select File» de la page ElegantOTA Lite.
Récupérer le fichier « update.bin » sur votre smartphone ou ordinateur puis valider.
Le station devrait redémarrer après la mise à jour.

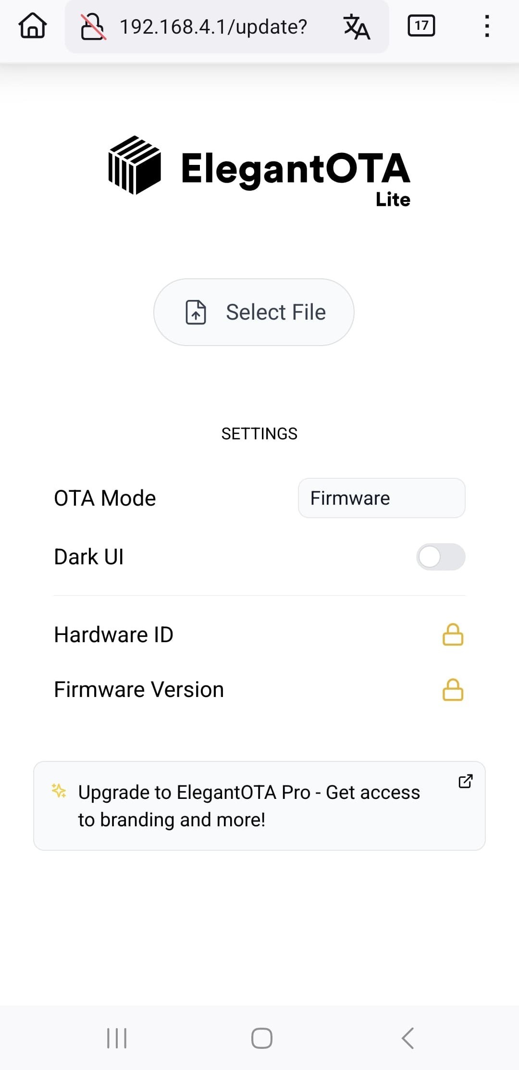
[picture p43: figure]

### Mise à jour du nom des balances

Afin de pouvoir identifier les balances sur internet, chaque station et balance sont nommées d’un identifiant unique. Le code étant commun à toute les balances, un nom est donné à la première utilisation. Ce nom reste en mémoire, même après une mise à jour du code.
Attention : Si vous changez le nom de la station, les valeurs des balances ne seront plus consultable à distance.

### Mise à jour du serveur et port MQTT :

Fonctionnement actuel (mai 2025) :
Envoi des données par Nb-iot via le réseau Bouygues Telecom (abonnement sim à renouveler tous les ans)
Broker MQTT Mosquitto privé herbergé sur un raspberry pi 5.
Transmission via le module Telegraf des données vers la base de données Influxdb V2 herbergée sur un raspberry pi 5.
Visualisation sur Grafana dans le cloud. Grafana, vient récupérer les données sur le raspberry 5.

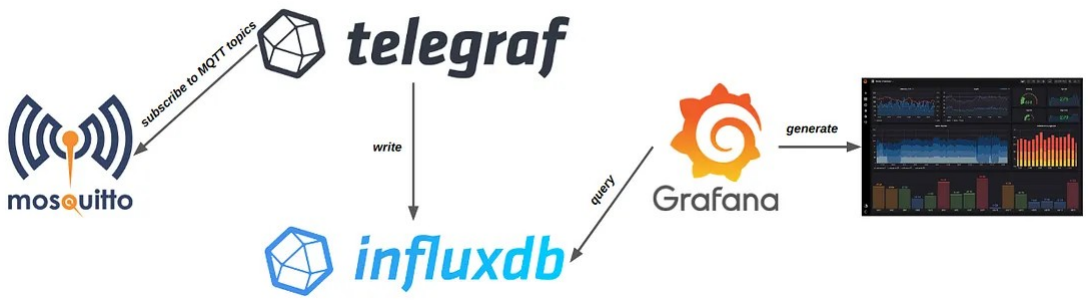
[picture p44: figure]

Cette solution de stockage de données et visualisation est donc « gratuite » pour l’utilisateur et je supporte seul le coup du matériel. Vous voulez me payer un café, mon lien paypal ci dessous, merci !
https://paypal.me/GNUVarioE?country.x=FR&locale.x=fr_FR

Si vous ne souhaitez plus passer par ce système, créer votre propre installation ou passer par une solution 100 % cloud mais probablement payante, vous pouvez modifier l’adresse et le port du broker MQTT.

### Divers :

Après chaque émission, la station se met en mode sommeil profond afin d’économiser de la batterie. Après chaque émission, la led clignote.
La fréquence des émissions est fonction de la charge de la batterie :
30 minutes de 100 % à 76 %
2h entre 75 % et 51 %
6h entre 50 % et 26 %
12 h sous les 25 %
Pensez à positionner le panneau solaire sur le toit de la ruche, face du panneau vers le sud.

Il est possible que dans certaines conditions, la station ait du mal à se connecter au réseau GSM. Dans ce cas, pour ne pas vider la batterie, la station se met en sommeil profond au bout de 60s.
Si la station ne se connecte jamais, il est possible de déconnecter la petite antenne et de la remplacer par une antenne plus grande avec un long fil. Vous pourrez ainsi essayer d’accrocher l’antenne un point plus haut (toit de la ruche, branche…).

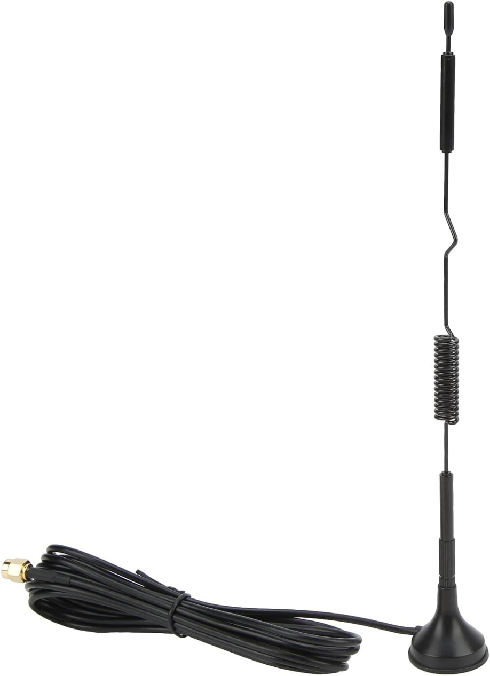
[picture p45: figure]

Les cellules des balances supportent 100kg. Elles fonctionneront avec un peu plus dessus mais pensez lorsque vous les changez de place à vérifier les vis de fixation ( les 8 vis M6 sur les pesons et les vis des équerres entre les profilés alu).
Si les balances ne sont pas utilisées, éteigniez les et gardez les à l’ombre pour ne pas exposer inutilement le boîtier au soleil.
Si vous déconnectez les balances ou le panneau solaire, pensez à obturer les connecteurs avec leur capuchon afin de les protéger.

Bref, prenez soin de votre matériel.

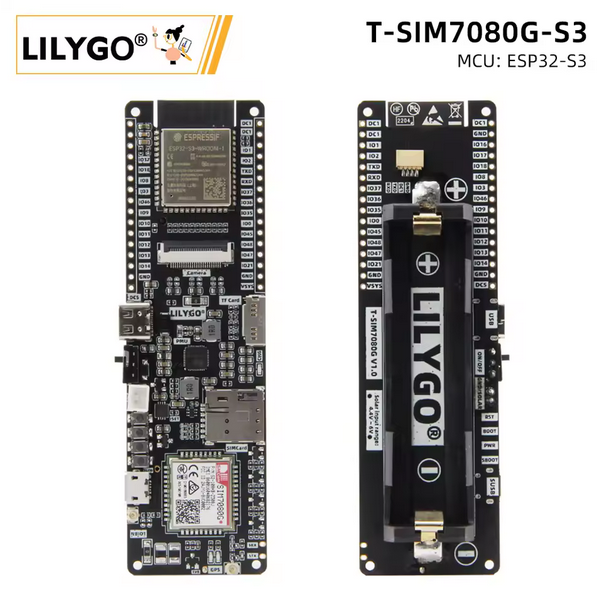
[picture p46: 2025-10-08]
Balance Nb_iot/images/TTGO.png

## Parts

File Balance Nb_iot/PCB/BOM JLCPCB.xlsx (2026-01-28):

Comment | Designator | Footprint | JLCPCB Part #（optional）
Conn_01x12 | J3 | 1989845 | C17674443
ATtiny202-SS | U1 | SOIC-8_3.9x4.9mm_P1.27mm | C2052951
4.7k | R12,R10,R1 | R_0603_1608Metric | C513565
1k | R11 | R_0603_1608Metric | C110776
PMBT2222A,215 | Q4,Q1 | PMBT2222A215 | C23869
1µF/16V | C16 | C_0603_1608Metric | C161212
0.1µF | C7,C2,C6,C9,C11,C10,C5,C12,C8,C1,C15 | C_0603_1608Metric | C45000
10µF | C13,C4,C3,C14 | C_0805_2012Metric | C408142
HX711 | IC2,IC1 | SOIC127P600X160-16N | C43656
MMBT4403 | Q2,Q3 | PMBT2222A215 | C78864
100 | R9,R8,R5,R4 | R_0603_1608Metric | C122970
20K | R6,R2 | R_0603_1608Metric | C723637
8.2K | R3,R7 | R_0603_1608Metric | C861589
3.3µH | L1,L2 | L_0603_1608Metric | C1857984
Conn_01x05 | J14,J12 | 1989777 | C17643135

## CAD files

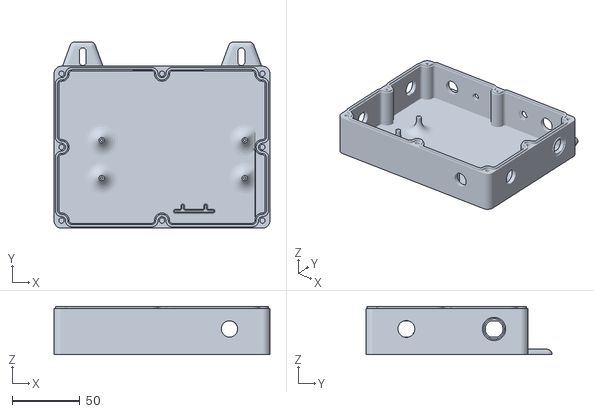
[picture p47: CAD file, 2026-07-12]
Balance Nb_iot/Fichiers stl/Boitier TTGO V4.STL
160.0 x 138.0 x 35.7

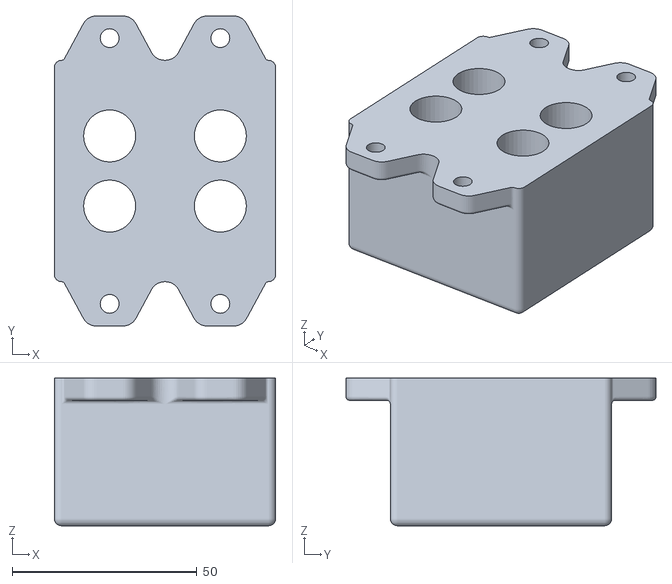
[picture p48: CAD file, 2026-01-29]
Balance Nb_iot/Fichiers stl/Gabarit de perçage.STL
60.0 x 84.0 x 40.0

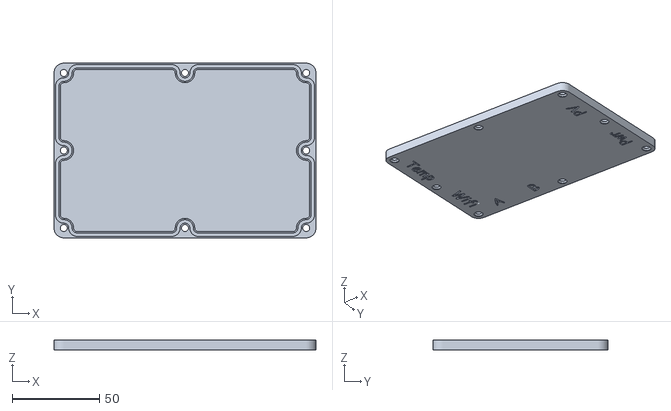
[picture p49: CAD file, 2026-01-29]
Balance Nb_iot/Fichiers stl/Couvercle TTGO.STL
150.0 x 100.0 x 6.00

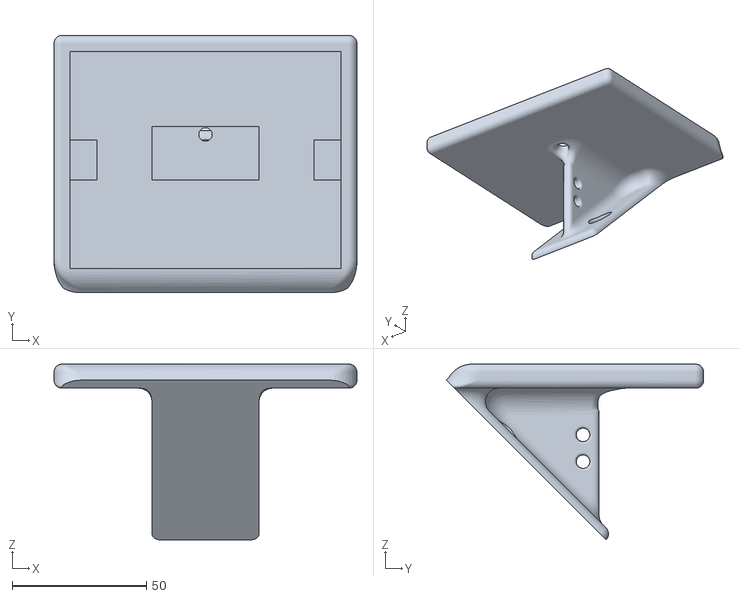
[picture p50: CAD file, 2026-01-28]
Balance Nb_iot/Fichiers stl/Support panneau solaire.STL
113.0 x 96.0 x 65.6

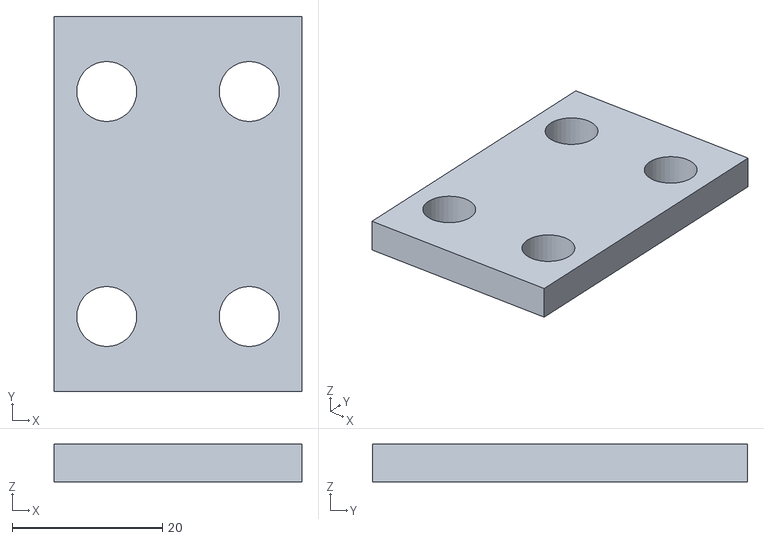
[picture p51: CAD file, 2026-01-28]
Balance Nb_iot/Fichiers stl/Entretoise balance.STL
33.0 x 50.0 x 5.00

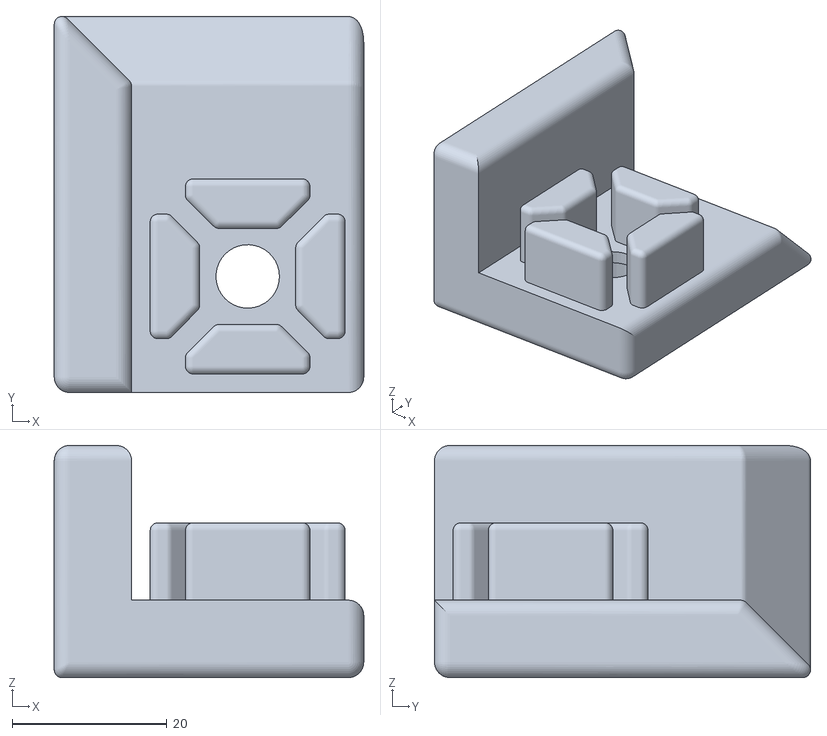
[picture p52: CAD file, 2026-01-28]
Balance Nb_iot/Fichiers stl/Blocage plateau AR court G.STL
40.0 x 48.6 x 30.0

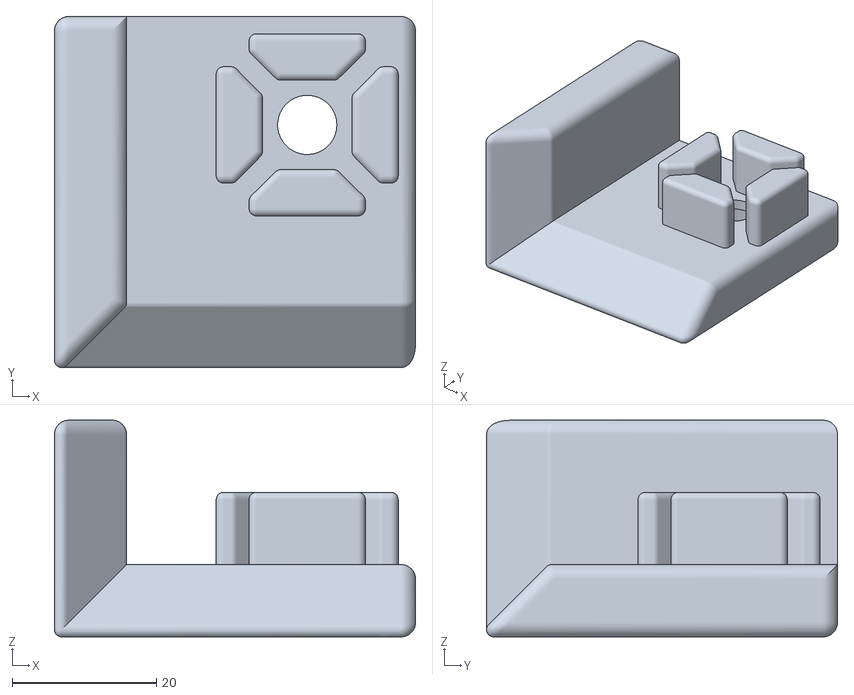
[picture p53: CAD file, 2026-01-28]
Balance Nb_iot/Fichiers stl/Blocage plateau AR long D.STL
50.0 x 48.6 x 30.0

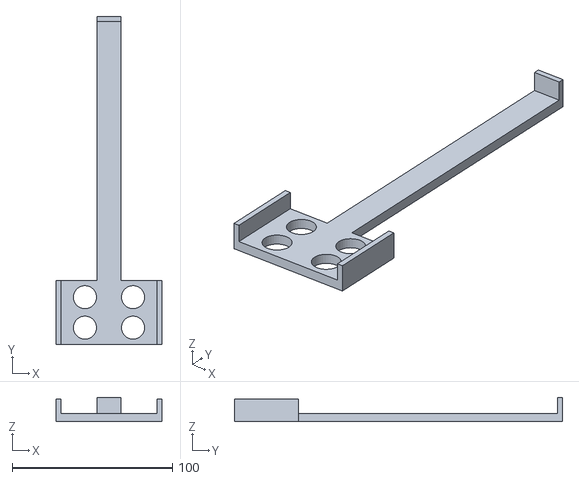
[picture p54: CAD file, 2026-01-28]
Balance Nb_iot/Fichiers stl/gabarit percage profilé 14mm.STL
66.0 x 204.5 x 15.0

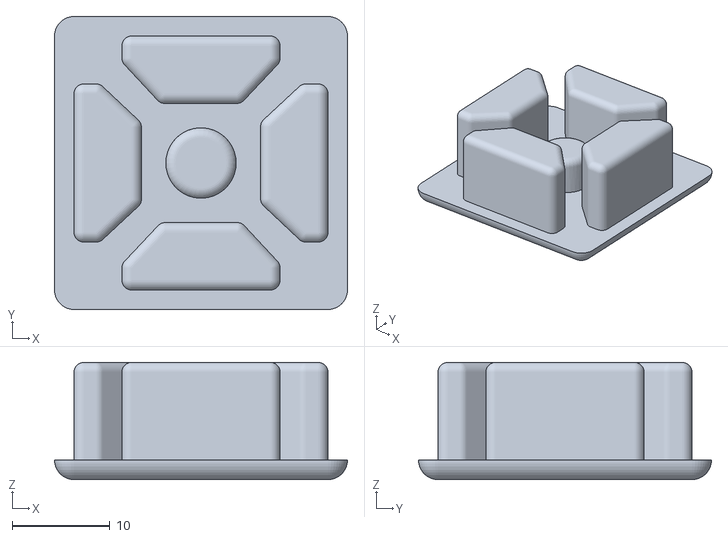
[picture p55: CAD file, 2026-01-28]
Balance Nb_iot/Fichiers stl/Bouchon bas balance.STL
30.0 x 30.0 x 12.0

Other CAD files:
Balance Nb_iot/Fichiers stl/Boitier TTGO V4 sans sma.STL
Balance Nb_iot/Fichiers stl/Blocage plateau AR court D.STL
Balance Nb_iot/Fichiers stl/Blocage plateau AR long G.STL

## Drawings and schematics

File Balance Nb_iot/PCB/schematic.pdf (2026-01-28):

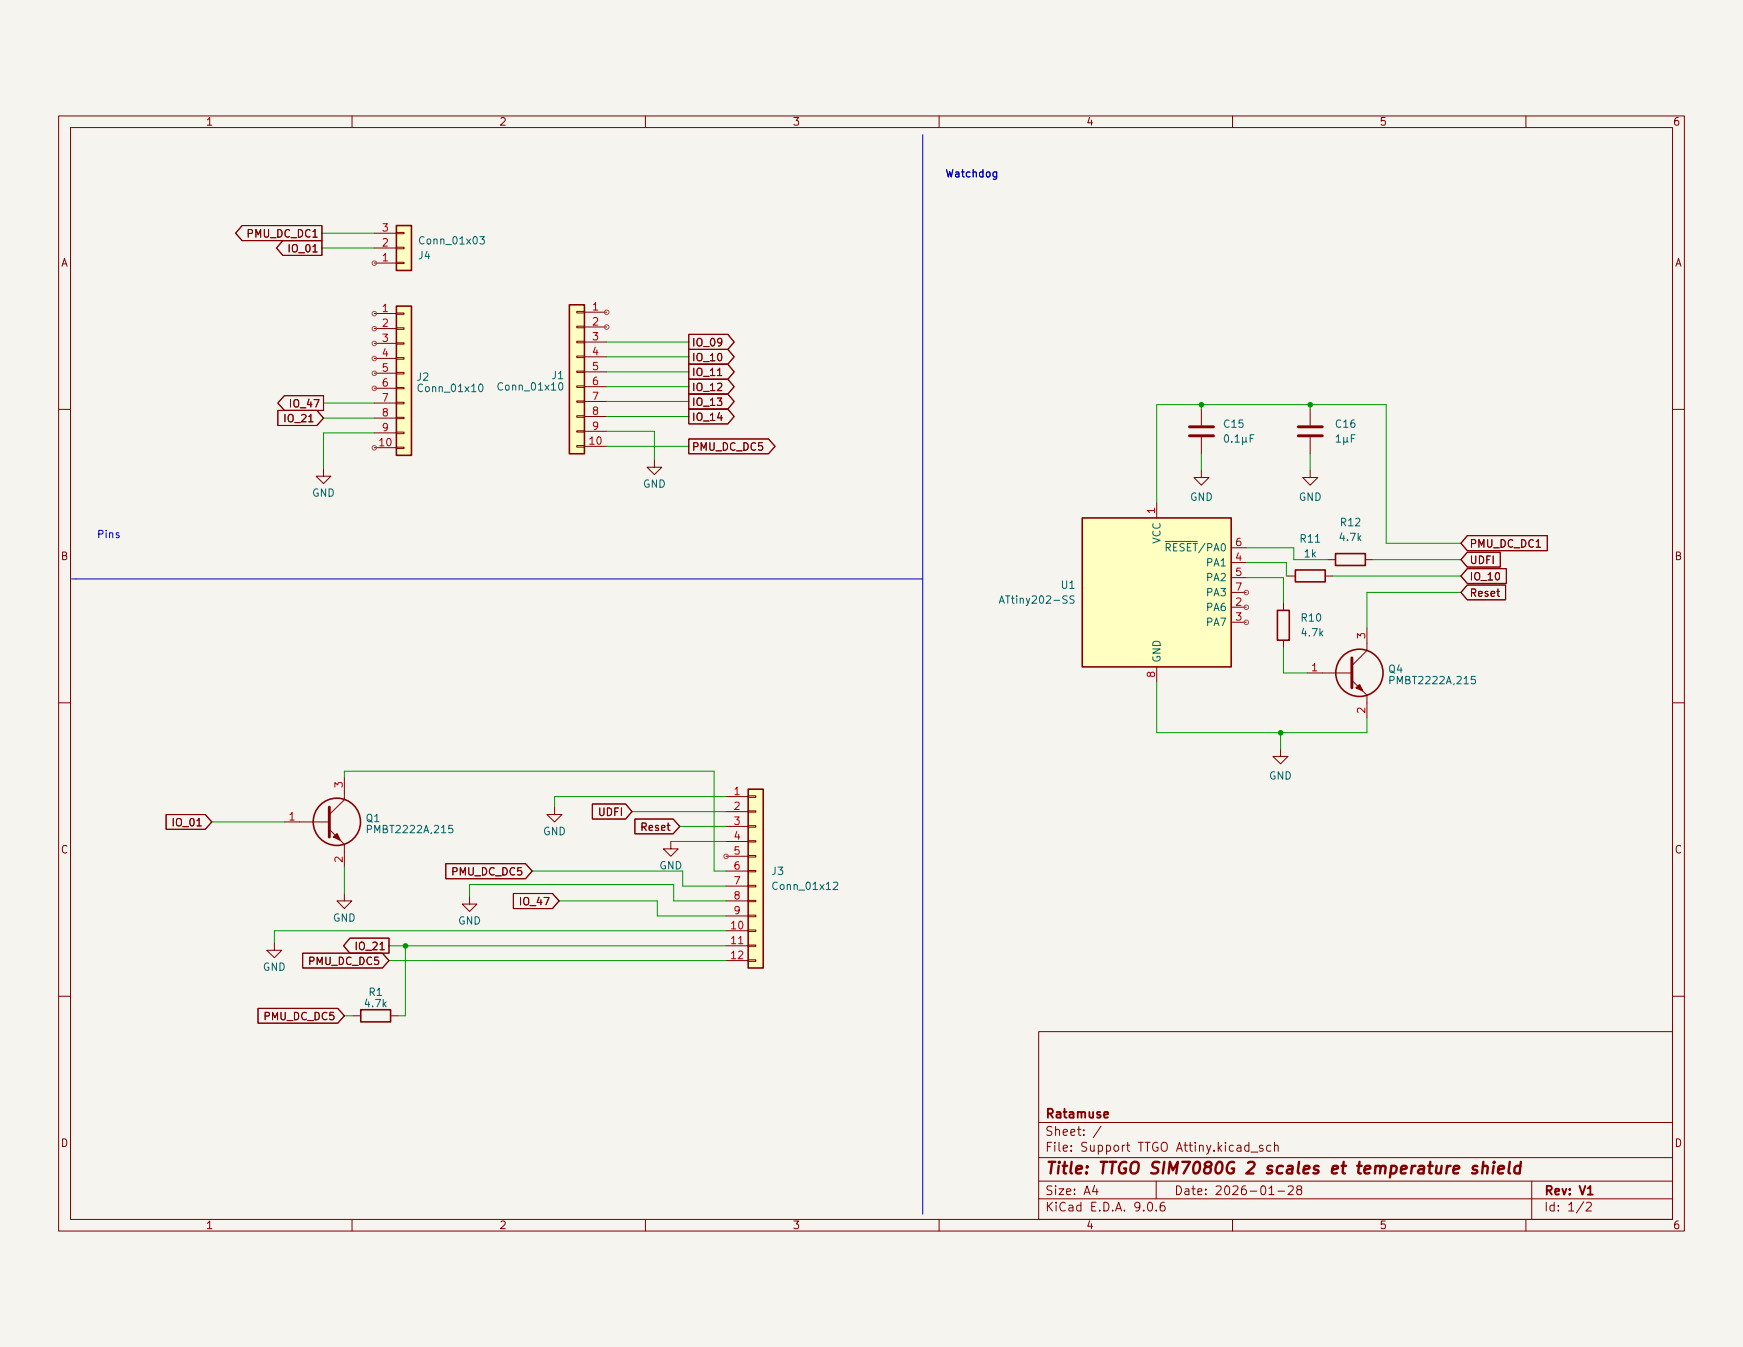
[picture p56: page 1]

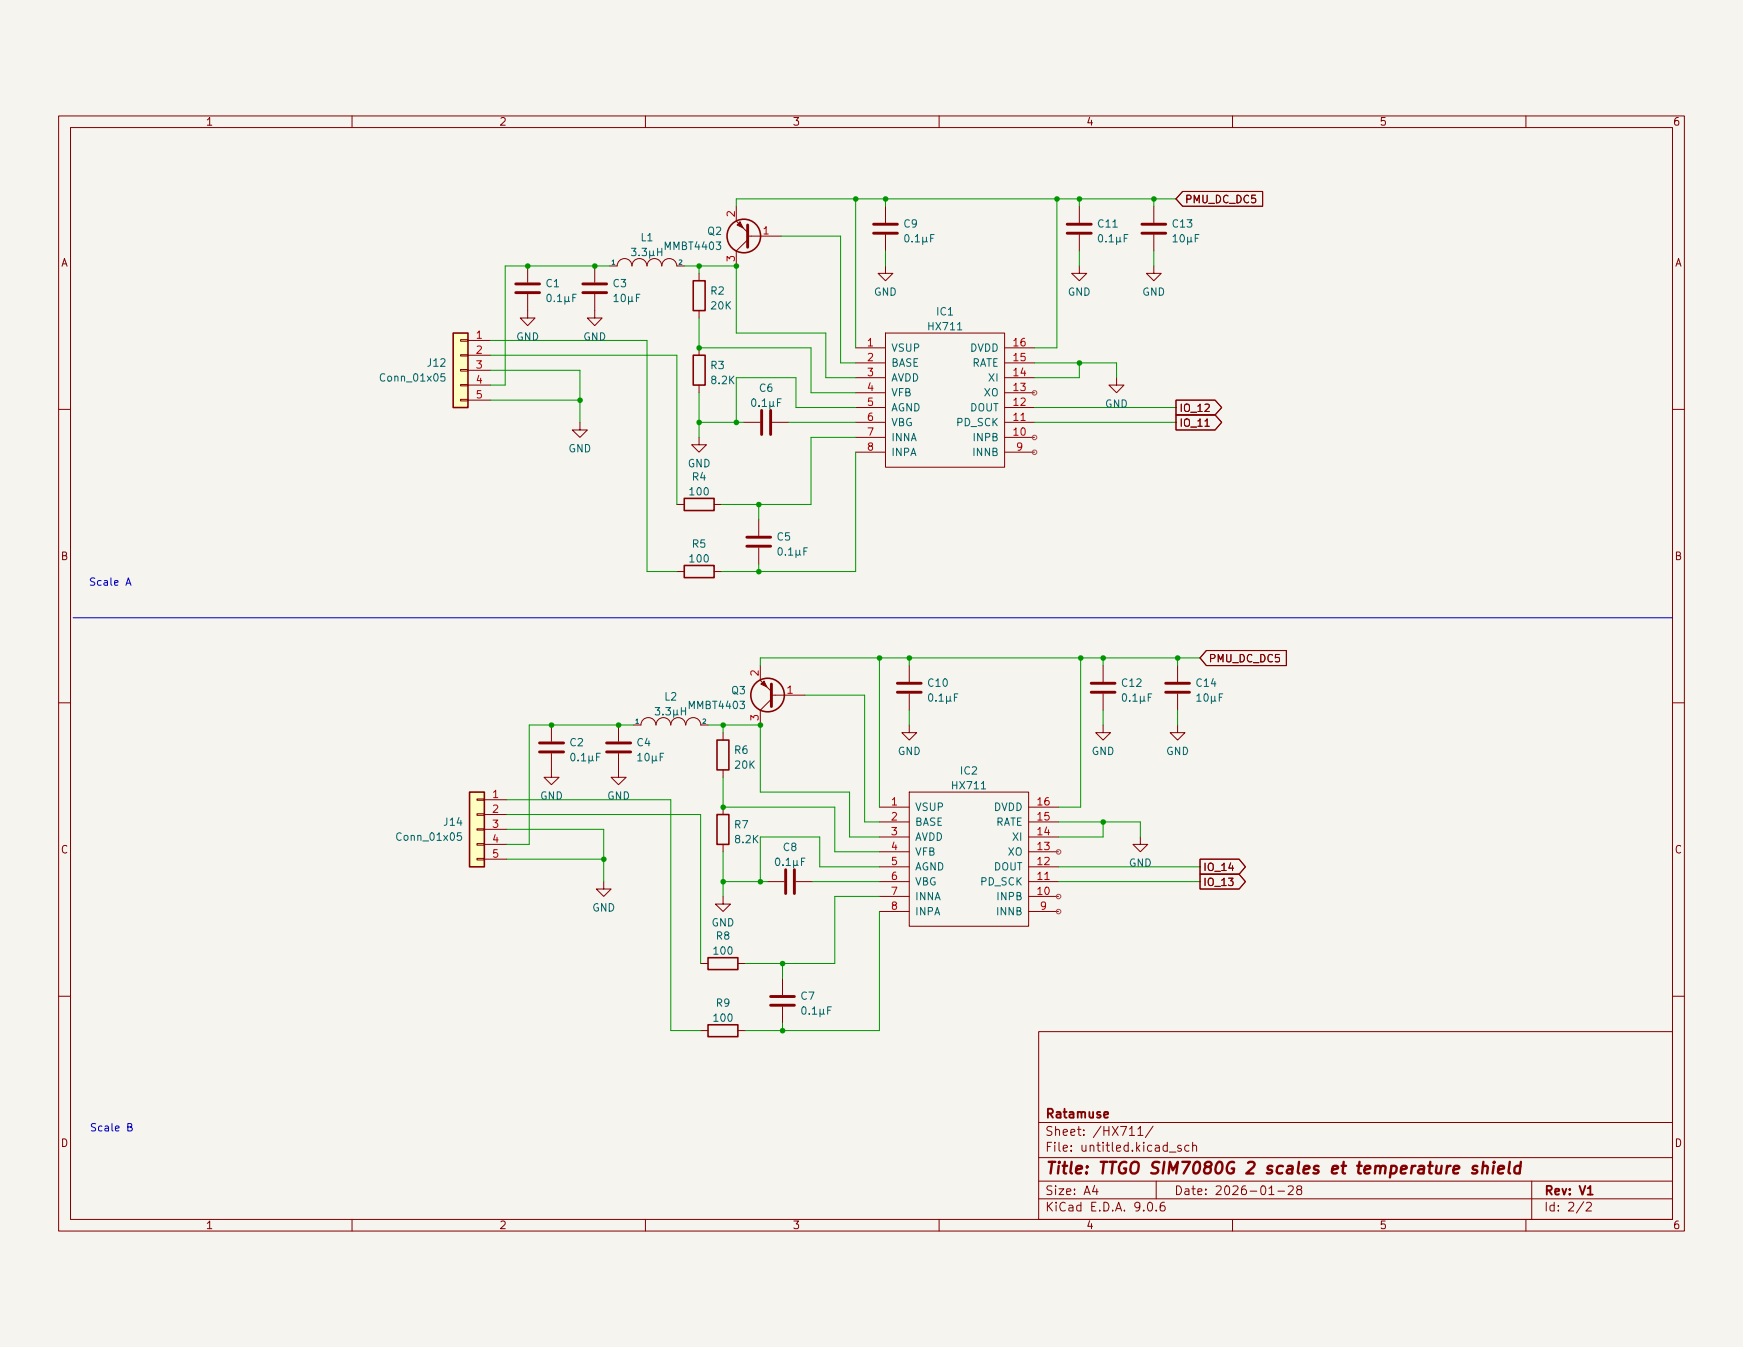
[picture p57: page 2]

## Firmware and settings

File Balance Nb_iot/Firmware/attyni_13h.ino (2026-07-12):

#include <Arduino.h>

// ================= CONFIG =================
#define HEARTBEAT_PIN   PIN_PA1
#define RESET_PIN       PIN_PA2

// Période inchangée : 31.25 ms (32 Hz)
#define RTC_PERIOD RTC_PERIOD_CYC1024_gc

// Calcul pour 14 heures :
// 14h × 3600s × 32Hz = 1,612,800 ticks
#define HEARTBEAT_TIMEOUT_TICKS 1612800UL // 'UL' pour unsigned long

#define RESET_PULSE_TICKS       16     // 500ms / 31.25ms = 16 ticks
#define DEBOUNCE_TICKS          2      // ~62.5ms

// ================= VARIABLES =================
volatile bool heartbeatDetected = false;
volatile uint32_t timeoutCounter = 0;    // CHANGÉ : 32 bits !
volatile uint16_t resetPulseCounter = 0;
volatile bool resetActive = false;

// ================= RTC PIT ISR =================
ISR(RTC_PIT_vect) {
  RTC.PITINTFLAGS = RTC_PI_bm;
  
  // Gestion timeout
  if (heartbeatDetected) {
    timeoutCounter = 0;
    heartbeatDetected = false;
  } else {
    if (timeoutCounter < HEARTBEAT_TIMEOUT_TICKS) {
      timeoutCounter++;
    }
  }
  
  // Déclenchement reset
  if (timeoutCounter >= HEARTBEAT_TIMEOUT_TICKS && !resetActive) {
    resetActive = true;
    resetPulseCounter = 0;
    PORTA.OUTSET = PIN2_bm;  // Activer RESET
  }
  
  // Gestion impulsion RESET
  if (resetActive) {
    if (resetPulseCounter >= RESET_PULSE_TICKS) {
      PORTA.OUTCLR = PIN2_bm;  // Désactiver RESET
      resetActive = false;
      timeoutCounter = 0;
      heartbeatDetected = true;  // Réarmer
    } else {
      resetPulseCounter++;
    }
  }
}

// ================= HEARTBEAT ISR =================
ISR(PORTA_PORT_vect) {
  if (PORTA.INTFLAGS & PIN1_bm) {
    heartbeatDetected = true;
    PORTA.INTFLAGS = PIN1_bm;
  }
}

// ================= SETUP =================
void setup() {
  // Configuration IO
  PORTA.DIRSET = PIN2_bm;    // PA2 en sortie
  PORTA.DIRCLR = PIN1_bm;    // PA1 en entrée
  PORTA.OUTCLR = PIN2_bm;    // PA2 à LOW
  
  // Pull-up + interruption sur front montant
  PORTA.PIN1CTRL = PORT_PULLUPEN_bm | PORT_ISC_RISING_gc;
  
  // Configuration RTC PIT
  while (RTC.STATUS > 0);  // Attendre synchronisation
  
  RTC.CLKSEL = RTC_CLKSEL_INT32K_gc;     // Source: OSCULP32K interne
  RTC.PITCTRLA = RTC_PERIOD | RTC_PITEN_bm;
  RTC.PITINTCTRL = RTC_PI_bm;
  
  // Initialisation
  heartbeatDetected = true;
  timeoutCounter = 0;
  resetActive = false;
  
  sei();
}

// ================= LOOP =================
void loop() {
  // Tout est géré dans les ISR
}

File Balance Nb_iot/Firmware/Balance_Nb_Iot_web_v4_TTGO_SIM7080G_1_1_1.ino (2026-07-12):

/*
  Balance_Nb_Iot_web_v4_TTGO_SIM7080G_mqtt_gps_V1.1.1.ino

  CORRECTIONS (2026-04-20) — v1.1.1 :
  ✅ Commande MQTT set_config : change serveur et/ou port MQTT à distance
     → Payload : {"action":"set_config","port":1886,"server":"nouveau.domaine.fr"}
     → Les deux champs sont optionnels (l'un ou l'autre suffit)
     → Sauvegarde en NVS, efface le retained /cmd, ACK, puis redémarrage
     → Disponible via le bouton ⚙️ Config MQTT du FOTA UI
  ✅ Ajout ICCID (numéro de carte SIM) dans le message JSON diagnostics
     → Lecture manuelle AT+CCID (getSimCCID() retournait "OK" sur SIM7080G)
     → Stocké dans la variable globale simICCID (String)
     → Publié dans le topic diagnostics : {"firmware":...,"iccid":"89330..."}
     → Permet d'identifier la carte SIM associée à chaque balance à distance

  CORRECTIONS (2026-04-13) — v1.1.0 :
  ✅ Pages "Calibration Réussie" (balance 1 et balance 2) :
     → Boutons "Tester la balance" et "Retour au menu" enveloppés dans un div flex
     → display:flex + gap:12px + flex-wrap:wrap + justify-content:center
     → Affichage correct sur smartphone (plus de débordement/chevauchement)

  CORRECTIONS (2026-03-10) :
  ✅ PMU DC3 réactivé : PMU.setDC3Voltage(3000) + PMU.enableDC3() dans
     setupNormalInit(), setupAPModeInit() et stabilizePower()
     → Alimentation SIM7080G restaurée (modem ne répondait plus à AT)
  ✅ Ack FOTA/Reset non-retained : retained=false sur topic /cmd/ack
     → Le message d'accusé de réception ne persiste plus sur le broker
  ✅ Témoin visuel FOTA (fota.cpp) : clignotement LED pendant le download
     → 1 flash court (150ms) + 1 flash long (400ms) par seconde
     → LED éteinte à la fin (succès ou échec)

  AJOUT RESET + FOTA (2026-03-07) — backport depuis v1.0.16 :
  ✅ Reset à distance via MQTT : {"action":"reset"} sur topic /cmd
     → Remet à zéro crash_count + fota_retry en NVS (pas de redémarrage)
  ✅ Nouveaux fichiers : fota.h, fota.cpp (copiés depuis v1.0.16)
     → Téléchargement firmware via TCP mux0 (TinyGsmClient)
     → Plus de conflit de mux : mqtt.disconnect() + client.stop() avant fotaExecute
     → Vérification MD5 + taille avant reboot
     → Compteur de tentatives NVS (max 10)
  ✅ mqttCallback() : parse la commande JSON {"action":"ota","url":"...","md5":"...","size":...}
  ✅ safeMQTTConnect() : setBufferSize(512) + setCallback(mqttCallback)
  ✅ Topic commande : deviceId + "/cmd"  (ex: E0D16CE6FC84/cmd)
  ✅ Topic ack : deviceId + "/cmd/ack"
  ✅ Bloc FOTA dans mainLoop() : subscribe 3s → execute → ack → restart si succès
  ✅ Commande reset : {"action":"reset"} → remet à zéro crash_count + fota_retry en NVS
     → Pas de redémarrage, le cycle continue normalement après le reset
  ✅ Stack appTask : 10000 → 20000 octets
  ✅ Page web /fota : monitoring état FOTA + reset compteur NVS + lien menu principal

  CORRECTION (2026-03-05):
  ✅ Calibration en 2 étapes avec tare automatique :
     → Étape 1 : balance vide → tare automatique (raw_zero mesuré et transmis)
     → Étape 2 : poser le poids connu → calcul du facteur avec le raw_zero de l'étape 1
     → Le raw_zero est également stocké comme offset (plus besoin de faire la tare séparément)
     → Suppression de la dépendance à l'offset précédemment stocké lors de la calibration
  ✅ Migration vers méthodes natives bibliothèque HX711 (Rob Tillaart v0.6.3) :
     → Calibration : tare(20) + calibrate_scale(poids, 20) → plus précis (20 lectures vs 10)
     → Calibration réduite de 3 pages à 2 pages (tare automatique sur chargement)
     → Tare manuelle : tare(10) au lieu de read_average(10) manuel
     → Mesure : get_units(10) au lieu de (raw - offset) / factor manuel
     → Initialisation : set_offset() ajouté après set_scale() au démarrage

  CHANGEMENTS v1.0.13:
  ✅ Configuration réseau NB-IoT/LTE-M explicite dans safeModemStart()
     → AT+CFUN=0 (mode avion) avant configuration
     → AT+CMNB=2 (NB-IoT uniquement, forfait Bouygues NB-IoT)
     → AT+CBANDCFG="NB-IOT",20 (bande B20 800MHz Bouygues)
     → AT+CGDCONT=1,"IP","" (APN vide, attribué auto par réseau: ido.net)
     → AT+CEREG=2 (infos étendues: TAC, Cell ID, AcT)
     → AT+CFUN=1 puis AT+COPS=0 (réactivation radio + opérateur auto)
  ✅ safeNetworkConnect() : surveillance CEREG directe (NB-IoT/LTE-M)
     → Parse manuelle de +CEREG pour détecter stat=1 (home) ou stat=5 (roaming)
     → Fallback TinyGSM getRegistrationStatus() en parallèle
     → Polling toutes les 5s avec messages de debug
  ✅ AT+CNETLIGHT=0 : désactivation LED modem
  ✅ AT+CMEE=2 : erreurs AT verbose pour diagnostic
  ✅ Gestion PDP auto-activé : détecte si +APP PDP: 0,ACTIVE après l'attach
     → Vérifie isGprsConnected() avant de tenter CNACT=0,1
     → Vide le buffer URC avant les commandes CNACT
     → Reset CNACT=0,0 avant retry si état incohérent

  CHANGEMENTS v1.0.12:
  ✅ Authentification MQTT : credentials générés automatiquement depuis eFuse MAC
     → Username : "bal_" + 8 caractères hex du MAC (ex: "bal_A1B2C3D4")
     → Password : hash déterministe 16 caractères hex basé sur le MAC complet
     → Reproductible : mêmes credentials à chaque boot pour un même ESP32
     → Non modifiable : sécurité par design, pas de mot de passe en dur
  ✅ mqtt_user / mqtt_pass : changés de const char* vides à String générés
  ✅ safeMQTTConnect() : utilise les credentials générés (au lieu de chaînes vides)
  ✅ Interface web : affiche les identifiants MQTT (user + password) sur la page d'accueil
  ✅ Page config MQTT : affiche les credentials en lecture seule avec instructions
     → Permet de copier facilement user/pass pour configurer le broker MQTT

  CHANGEMENTS v1.0.11:
  ✅ ID unique station : basé sur eFuse MAC ESP32-S3 (12 caractères hex)
  ✅ Topics MQTT : format deviceId/deviceName/<>/topic/<>/data/0
     → deviceId garantit l'unicité (filtrage Telegraf)
     → deviceName reste modifiable pour la lisibilité
  ✅ WiFi SSID : "balance" + deviceName (lisible, modifiable)
  ✅ Interface web : affiche ID station (fixe) + nom station (modifiable)
  ✅ Évite collisions : plusieurs stations peuvent avoir le même nom

  CHANGEMENTS v1.0.10 (Version finale pour déploiement):
  ✅ Watchdog optimisé : suppression tâches surveillance inutiles
  ✅ TWDT timeout 6 min (pour GPS 3 min max)
  ✅ Deep sleep 12h conservé (économie batterie optimale)
  ✅ Heartbeat simplifié : 2× par cycle (réveil + avant sleep)
  ✅ Preferences : gestion mode RO/RW corrigée
  ✅ Preferences : ReadOnly par défaut pour lectures
  ✅ Preferences : Écritures boot_count réduites (8× → 1×/jour)
  ✅ Preferences : Récupération automatique si corruption NVS
  ✅ Preferences : Validation après écritures critiques
  ✅ Validation données capteurs (NaN, Inf, ranges)
  ✅ Diagnostics MQTT améliorés
  ✅ DUMP_AT_COMMANDS conservé (debug essentiel)

*/

#include <Arduino.h>
#include <ArduinoJson.h>
#include "esp_task_wdt.h"
#include "esp_system.h"
#include "esp_timer.h"
#include "esp_heap_caps.h"
#include "nvs_flash.h"
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

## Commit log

2026-01-28 Update pcb.jpg
    update pcb
2026-01-28 update pcb files
    [BOM JLCPCB.xlsx, JLCPCB.xlsx]
2026-01-28 Update PCB link for scale circuit files
2026-01-28 Fix link for PCB files in README.md
2026-01-28 update stl file
    [Blocage plateau AR court D.STL, Blocage plateau AR court G.STL, Blocage plateau AR long D.STL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]
2026-01-28 Update STL file link in README
2026-01-28 Update assembly guide link in README
2026-01-28 Revise project documentation and cost estimation
    Updated the table of contents, added cost estimation sections, and revised assembly steps. Enhanced clarity and organization of project documentation.
2026-01-28 Update README with web server details
    Added information about the embedded web server for calibration and MQTT configuration.
2026-01-28 Update connector description in README
2026-01-29 update stl
    [Boîtier TTGO.STL, Couvercle TTGO.STL, TTGO_v3_boitier_V2.STL]
2026-01-29 Create Gabarit de perçage.STL
    [Gabarit de perçage.STL]
2026-01-29 Update Gabarit de perçage.STL
    [Gabarit de perçage.STL]
2026-03-28 Add missing 'Vis de boîtier' entry in materiel.md

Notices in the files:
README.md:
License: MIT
